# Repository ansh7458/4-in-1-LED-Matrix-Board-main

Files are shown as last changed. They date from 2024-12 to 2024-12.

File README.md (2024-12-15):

# 🎮 4-in-1 LED Matrix Board

<p align="center">
  
  
  
  
  
</p>

> **Centre for Electronic Design and Technology**  
> Netaji Subhas University of Technology, New Delhi  
> *Date: December 2024*

---

## 📋 Table of Contents
- [Synopsis](#-synopsis)
- [Introduction](#-introduction)
- [System Overview](#-system-overview)
- [Working Modes](#-working-modes)
- [Program Logic](#-program-logic)
- [Inputs & Control](#-inputs--control)
- [Bill of Materials](#-bill-of-materials)

---

## 🎯 Synopsis

A compact and multifunctional **5×7 LED dot matrix system** built around an **Arduino Nano**. It integrates **four interactive modules** into a single educational platform:

- 🔤 **Morse Tutor** — Learn Morse code interactively
- ⏳ **LED Hourglass** — Tilt-controlled sand animation
- 👁️ **Persistence of Vision (POV) Demo** — Visual persistence effect
- 🌡️ **Temperature Display** — Real-time thermistor reading

User interaction is achieved via **buttons**, **tilt switches**, and a **potentiometer**. The system leverages **Timer1 CTC interrupts** for flicker-free LED multiplexing.

## 📖 Introduction

LED matrices are widely used in educational and commercial applications. This project creates a single, compact platform that consolidates multiple mini-projects, enabling learners to explore different aspects of embedded system design:

| Mode | Concept Demonstrated |
|---|---|
| Morse Tutor | Digital output control, timing-based signal generation |
| Hourglass | Tilt-sensor input handling, animation sequencing |
| POV Demo | Persistence-of-vision, real-time potentiometer control |
| Temperature | Analog sensor reading, calculation, text rendering |

## 🔧 System Overview

### Block Diagram
<p align="center">
  Block Diagram
</p>

### Pin Assignment (Arduino Nano)

| Pin | Signal | Connected To | Function |
|-----|---|---|---|
| D2-D8 | R1-R7 | ULN2003 | Row drives for LED matrix |
| D9-D13 | C1-C5 | BC327 transistors | Column drives |
| A1-A3 | BTN1-3 | Push Buttons | Navigation (Next/Prev/Select) |
| A4-A5 | Tilt 1-2 | Tilt Switches | Hourglass orientation |
| A6 | Thermistor | NTC | Temperature sensing |
| A7 | Pot | RV1 | POV speed control |

## 🎮 Working Modes

### 1. 🏠 Home Screen
Menu navigation using three push buttons (Next, Previous, Select). Long press (~5s) on Button 1 returns to home from any mode.

### 2. 🔤 Morse Tutor
Displays Morse code patterns for A–Z on the LED matrix with timing-based dot/dash rendering.

### 3. ⏳ Hourglass
Tilt-controlled sand animation with direction detection. Passive buzzer alerts when timer completes.

### 4. 👁️ POV Demo
Potentiometer controls Timer1 compare register, varying refresh frequency to demonstrate persistence-of-vision effect.

### 5. 🌡️ Temperature Display
NTC thermistor with **Beta parameter model** for temperature calculation, displayed as scrolling digits on the matrix.

## ⚙️ Program Logic

The firmware follows a **cooperative architecture**:
- **Foreground (main loop)**: User input processing, mode logic, display buffer updates
- **Background (Timer1 ISR)**: Column-wise LED multiplexing at high speed for flicker-free display

## 📦 Bill of Materials

| S.No | Component | Value | Qty |
|---|---|---|-----|
| 1 | Arduino Nano | — | 1 |
| 2 | 5×7 LED Matrix | — | 1 |
| 3 | ULN2003 | Darlington Array | 1 |
| 4 | BC327 | PNP Transistor | 5 |
| 5 | Push Buttons | — | 3 |
| 6 | Tilt Switches | — | 2 |
| 7 | NTC Thermistor | 10 kΩ | 1 |
| 8 | Potentiometer | — | 1 |
| 9 | Passive Buzzer | — | 1 |

## 🛠️ Technologies Used

`Arduino (C/C++)` · `KiCad` · `Timer Interrupts (CTC)` · `Embedded Systems` · `PCB Design`

## 👥 Author
- **Ansh Gupta** — NSUT, New Delhi

---
*Centre for Electronic Design and Technology, NSUT, New Delhi*

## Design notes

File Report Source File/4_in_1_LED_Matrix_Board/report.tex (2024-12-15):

\documentclass[12pt,a4paper]{article}

% ---------- Packages ----------
\usepackage[utf8]{inputenc}
\usepackage[T1]{fontenc}
\usepackage{lmodern}
\usepackage{geometry}
\geometry{margin=1in}
\usepackage{graphicx}
\usepackage{float}
\usepackage{caption}
\usepackage{subcaption}
\usepackage{siunitx}
\usepackage{booktabs}
\usepackage{array}
\usepackage{amsmath}
\usepackage{hyperref}
\hypersetup{colorlinks=true,allcolors=blue}
\usepackage{enumitem}
\usepackage{xcolor}
\usepackage{listings}
\usepackage{svg}

% ---------- Listings (Arduino/C++) ----------
\lstdefinelanguage{ArduinoC}{language=C++,morekeywords={String,bool,byte,word,bitSet,bitClear,bitWrite,bitRead,analogRead,digitalRead,digitalWrite,pinMode,INPUT,OUTPUT,INPUT_PULLUP,PROGMEM,ISR,cli,sei,tone,noTone}}
\lstset{
  language=ArduinoC,
  basicstyle=\ttfamily\small,
  keywordstyle=\color{blue!70!black}\bfseries,
  commentstyle=\color{gray!70},
  stringstyle=\color{green!50!black},
  showstringspaces=false,
  breaklines=true,
  frame=single,
  tabsize=2,
  captionpos=b,
  numbers=left,
  numberstyle=\tiny\color{gray}
}
\begin{document}
% ---------- Title ----------
\begin{titlepage}
  \begin{center}
    \vspace*{1cm}
    \\[0.5cm]
    {\Large \textbf{Centre for Electronic Design and Technology}}\\[0.25cm]
    {\large Netaji Subhas University of Technology, New Delhi}
    \vfill
    {\Huge \textbf{4-in-1 LED Matrix Board}}\\[0.3cm]
    \vspace{1.5cm}
    {\large \textbf{Submitted by}}\\[0.2cm]
    {\large Ansh Gupta}\\
    \vspace{0.8cm}
    {\large \textbf{Date:} December 2024}
    \vspace*{1cm}
  \end{center}
\end{titlepage}

\tableofcontents
\newpage

% =========================================================
\section{Synopsis}

The project presents a compact and multifunctional 5×7 LED dot matrix system built around an \textbf{Arduino Nano}. It integrates four interactive modules into a single educational platform:

\begin{itemize}
  \item Morse Tutor
  \item LED Hourglass
  \item Persistence of Vision (POV) Demo
  \item Temperature Display
\end{itemize}

User interaction is achieved via buttons, tilt switches, and a potentiometer. The system leverages \textbf{Timer1 CTC interrupts} for flicker-free LED multiplexing and responsive animations. This project serves as a practical tool for learning embedded systems concepts such as sensor interfacing, timer-based control, and display driving on a microcontroller platform.

\section{Introduction}

LED matrices are widely used in educational and commercial applications for visual feedback, animation, and information display. Designing an interactive LED dot matrix system provides hands-on experience in key embedded system concepts, including I/O management, timing control, and analog sensor interfacing.

The motivation behind this project is to create a single, compact platform that consolidates multiple mini-projects, enabling learners to explore different aspects of embedded system design in a cohesive setup. Each module of the system demonstrates a distinct concept:

\begin{itemize}
  \item \textbf{Morse Tutor:} Demonstrates digital output control and timing-based signal generation.
  \item \textbf{Hourglass:} Illustrates tilt-sensor input handling and animation sequencing.
  \item \textbf{POV Demo:} Explores persistence-of-vision techniques and real-time control using potentiometer input.
  \item \textbf{Temperature Display:} Combines analog sensor reading, calculation, and text rendering on a small LED dot matrix.
\end{itemize}

This report details the hardware and software design of the system, the logic behind each functional mode, and the observed performance, highlighting the educational value of integrating multiple embedded system principles into one device.

% =========================================================
\section{System Overview}
\subsection{Block Diagram}
\begin{figure}[H]
  \centering
  % Replace with your block diagram file
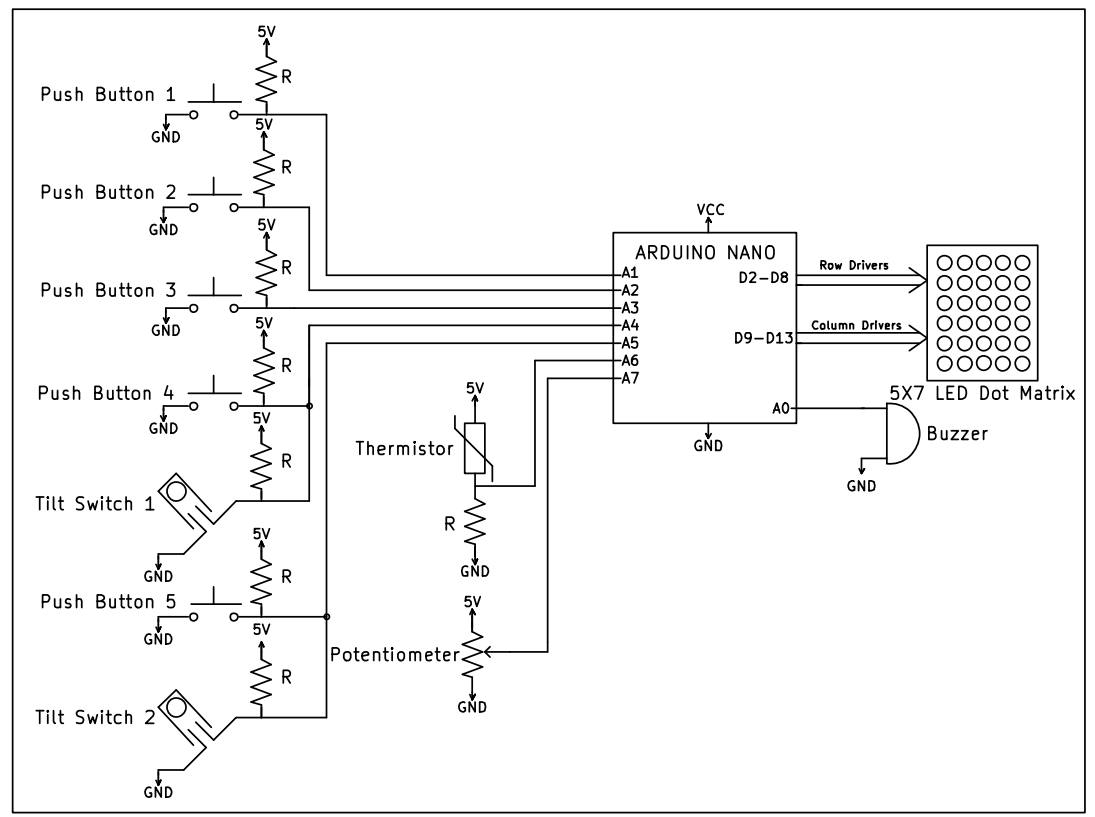
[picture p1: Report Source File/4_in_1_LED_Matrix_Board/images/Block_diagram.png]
  
  \caption{Block diagram}
  \label{fig:block}
\end{figure}

\subsection{Schematic Diagram}
\begin{figure}[H]
  \centering
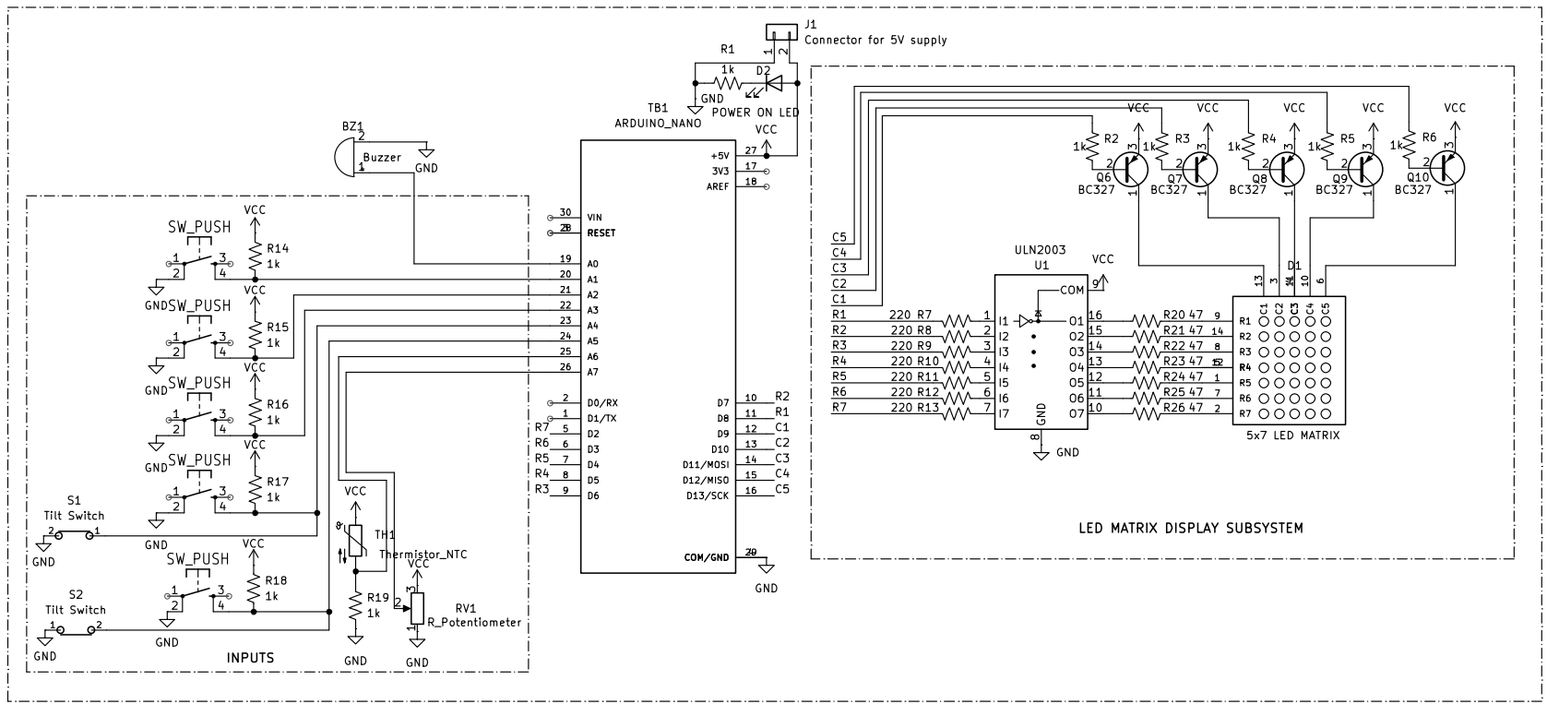
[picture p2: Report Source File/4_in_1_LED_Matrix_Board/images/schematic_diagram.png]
  
  \caption{Schematic Diagram}
  \label{fig:schematic}
\end{figure}
%=========================================================
\subsection{Pin Assignment Table}

Table~\ref{tab:pinout} summarizes the Arduino Nano pin assignments and their corresponding peripherals used in the 4-in-1 LED Matrix Board.

\begin{table}[H]
\centering
\caption{Arduino Nano Pin Assignment}
\label{tab:pinout}
\renewcommand{\arraystretch}{1.2}
\begin{tabular}{cllp{6.5cm}}
\toprule
\textbf{Pin} & \textbf{Signal} & \textbf{Connected To} & \textbf{Function} \\
\midrule

D2  & R7 & ULN2003 IN7 & Drives Row 7 of the LED matrix \\
D3  & R6 & ULN2003 IN6 & Drives Row 6 of the LED matrix \\
D4  & R5 & ULN2003 IN5 & Drives Row 5 of the LED matrix \\
D5  & R4 & ULN2003 IN4 & Drives Row 4 of the LED matrix \\
D6  & R3 & ULN2003 IN3 & Drives Row 3 of the LED matrix \\
D7  & R2 & ULN2003 IN2 & Drives Row 2 of the LED matrix \\
D8  & R1 & ULN2003 IN1 & Drives Row 1 of the LED matrix \\

D9  & C1 & Matrix Column 1 & Column drive through BC327 transistor \\
D10 & C2 & Matrix Column 2 & Column drive through BC327 transistor \\
D11 & C3 & Matrix Column 3 & Column drive through BC327 transistor \\
D12 & C4 & Matrix Column 4 & Column drive through BC327 transistor \\
D13 & C5 & Matrix Column 5 & Column drive through BC327 transistor \\

A0 & -- & Not Used & Reserved / unused \\

A1 & BTN1 & Push Button 1 & Home navigation (Next) \\
A2 & BTN2 & Push Button 2 & Home navigation (Previous) \\
A3 & BTN3 & Push Button 3 & Home navigation (Select) \\
A4 & Tilt 1 & Tilt Switch S1/ Push Button 4 & Hourglass tilt input \\
A5 & Tilt 2 & Tilt Switch S2/ Push Button 5 & Reverse hourglass tilt input \\
A6 & Thermistor & NTC Thermistor & Temperature sensing \\
A7 & Potentiometer & RV1 & Controls POV display speed \\

5V & VCC & All peripherals & Supply voltage \\
GND & GND & Entire circuit & Common ground \\

\bottomrule
\end{tabular}
\end{table}
% =========================================================
\section{Program Logic}
\begin{figure}[H]
  \centering
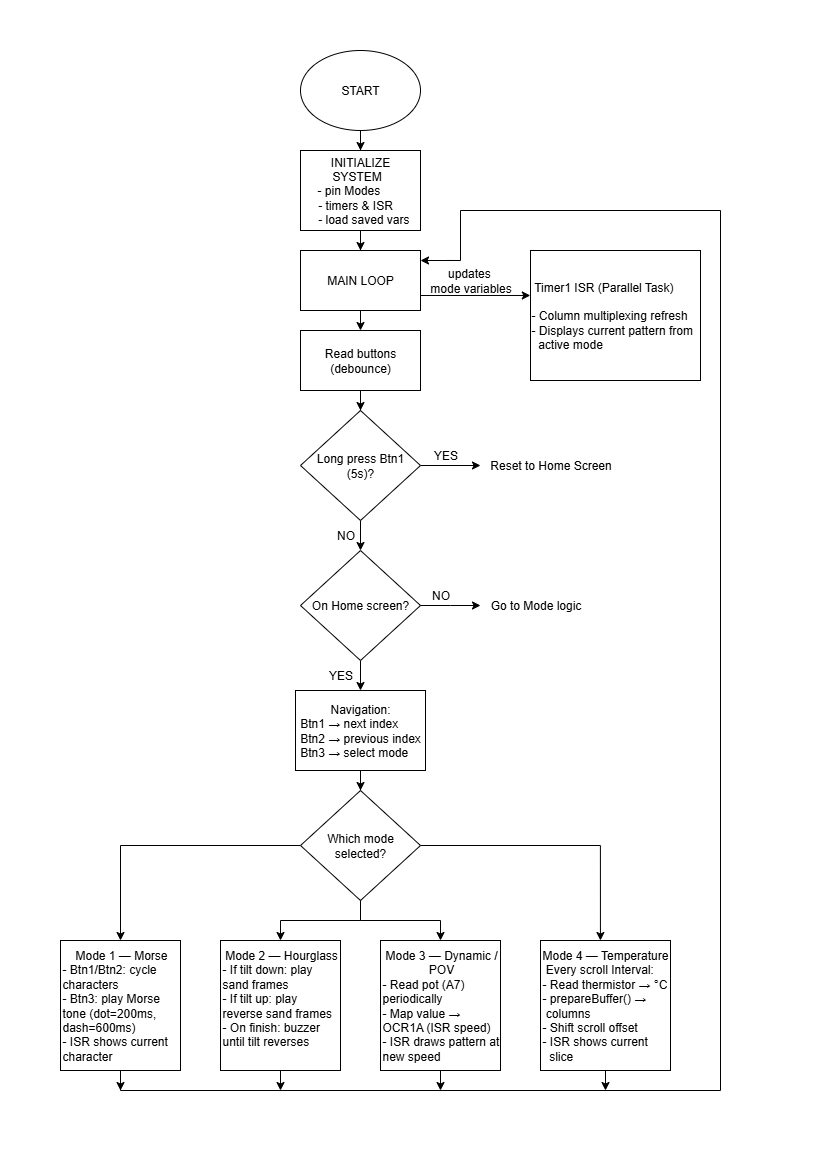
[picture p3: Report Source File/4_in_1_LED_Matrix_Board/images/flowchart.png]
  
  \caption{High-level program flowchart showing initialization, main loop logic, and Timer1 ISR operation.}
\end{figure}
\newpage
After power-up or reset, the firmware configures all GPIO pins, initializes global variables, computes the timing parameters required for animation modes, and configures \textbf{Timer1} in \textbf{Clear Timer on Compare (CTC)} mode. Timer1 generates periodic interrupts that continuously refresh the LED matrix using column-wise multiplexing, allowing the main program to execute application logic independently of display updates.

The firmware follows a cooperative architecture consisting of a foreground \textbf{main loop} and a background \textbf{Timer1 Interrupt Service Routine (ISR)}. The main loop is responsible for processing user inputs, updating mode-specific variables, and preparing display data, while the ISR performs high-speed multiplexing of the LED matrix to maintain a stable, flicker-free display.

The overall firmware operation is summarized below.

\begin{enumerate}[itemsep=4pt]

\item \textbf{Home Screen Navigation:}
When no application mode is active, the LED matrix displays the home screen. Three push buttons are used for menu navigation:
\begin{itemize}
    \item Button~1 -- Next mode
    \item Button~2 -- Previous mode
    \item Button~3 -- Select mode
\end{itemize}
A long press of Button~1 (approximately 5\,s) exits any running mode and returns the system to the home screen.

\item \textbf{Mode Execution:}
After a mode is selected, the corresponding application logic executes within the main loop.
\begin{itemize}
    \item \textbf{Mode 1:} Morse Tutor
    \item \textbf{Mode 2:} LED Hourglass
    \item \textbf{Mode 3:} Persistence of Vision (POV) Demo
    \item \textbf{Mode 4:} Temperature Display
\end{itemize}

\item \textbf{Background Display Refresh:}
The Timer1 ISR executes periodically throughout system operation. During each interrupt, one column of the LED matrix is refreshed by outputting the appropriate bitmap corresponding to the currently active mode. This interrupt-driven multiplexing ensures uniform brightness and prevents visible display flicker.

\item \textbf{Foreground Processing:}
While the ISR refreshes the display, the main loop continuously performs button debouncing, tilt-switch monitoring, potentiometer and thermistor acquisition, mode transitions, animation control, and updates the display buffer whenever the displayed content changes.

\end{enumerate}
\newpage
% =========================================================
\section{Inputs and Control Logic}
\subsection{Buttons and Navigation}

Three push buttons provide user interaction with the system. Each button is configured using the Arduino Nano's internal \texttt{INPUT\_PULLUP} resistor, eliminating the need for external pull-down resistors and ensuring a stable default logic HIGH state. Consequently, a button press is detected as a logic LOW (active LOW).

During Home Screen operation, Button~1 and Button~2 are used to navigate through the available modes, while Button~3 selects the highlighted mode. To improve usability, the firmware also detects a long press (approximately 5\,s) on Button~1, allowing the user to exit any active mode and return directly to the Home Screen.

\subsection{Tilt Interaction}

The Hourglass mode uses two tilt switches to detect the orientation of the board. Each switch is configured as an active LOW digital input using the Arduino Nano's internal pull-up resistor. Depending on the detected orientation, the firmware determines the direction of the sand animation.

\begin{itemize}[itemsep=2pt]
    \item When the board is tilted downward, the sand animation is played in the forward direction, simulating sand falling to the bottom chamber.
    
    \item When the board is tilted upward, the animation is played in the reverse direction, simulating the hourglass being inverted.
    
    \item After the final animation frame is displayed, the passive buzzer generates an audible alert. The alert continues until the board is tilted in the opposite direction or the mode is reset.
\end{itemize}
\textbf{Note:} The tilt switches are connected to Arduino Nano pins \textbf{A4} and \textbf{A5}, which are also routed to \textbf{Button~4} and \textbf{Button~5}, respectively, on the development board. These pins are dedicated to tilt sensing in the current implementation and are therefore not used as general-purpose push buttons.

\subsection{Potentiometer and Display Refresh Control}

The Persistence of Vision (POV) mode uses a potentiometer to provide real-time control over the display refresh rate. The potentiometer output is continuously sampled through the Arduino Nano's ADC, and the measured value is used to adjust the Timer1 compare register (\texttt{OCR1A}).

Modifying the Timer1 compare value changes the interrupt period, thereby varying the LED matrix refresh frequency. At higher refresh rates, the displayed character appears stable due to the persistence-of-vision effect, whereas lower refresh rates make the row-by-row multiplexing process visible. This provides an interactive demonstration of how refresh frequency influences the perceived display.
\newpage

\subsection{Thermistor and Temperature Calculation}

Temperature measurement is performed using an NTC thermistor connected in a voltage divider configuration with a fixed \SI{1}{k\ohm} resistor. The Arduino Nano measures the divider voltage using its ADC, from which the thermistor resistance is calculated. The resistance is then converted into temperature using the \textbf{Beta parameter model}, which provides a good balance between computational simplicity and measurement accuracy for NTC thermistors.

The thermistor resistance is calculated as

\[
R_\mathrm{th}=R_\mathrm{pullup}\frac{5-V}{V},
\]

where \(V\) is the measured divider voltage.

The temperature in Kelvin is then obtained using

\[
T(K)=
\frac{1}
{\dfrac{1}{T_0}+
\dfrac{1}{\beta}
\ln\left(\dfrac{R_\mathrm{th}}{R_0}\right)},
\]

where

\[
T_0=298.15~\mathrm{K}, \qquad
\beta=3950, \qquad
R_0=\SI{1}{k\ohm}, \qquad
R_\mathrm{pullup}=\SI{1}{k\ohm}.
\]

The calculated temperature is converted to degrees Celsius and formatted into a scrolling text buffer using the \texttt{prepareBuffer()} function before being displayed on the LED matrix.
\newpage

% =========================================================
\section{Working Modes}

\subsection{Home Screen}

The Home Screen serves as the primary user interface of the system. It displays five icons corresponding to the available operating modes: Home, Morse Tutor, Hourglass, Persistence of Vision (POV) Demo, and Temperature Display. Users can navigate between these icons using Button~1 and Button~2, while Button~3 selects the highlighted mode. A long press of Button~1 returns the system to the Home Screen from any active mode.

\begin{figure}[H]
  \centering
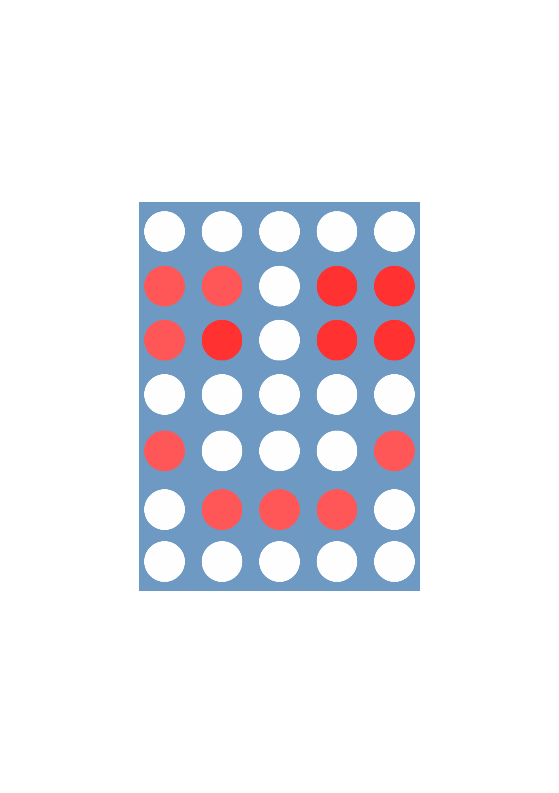
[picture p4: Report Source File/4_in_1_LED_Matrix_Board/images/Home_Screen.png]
  
  \caption{Home screen icons on the 5$\times$7 matrix.}
\end{figure}
\newpage
\subsection{Mode 1: Morse Tutor}

\begin{itemize}[itemsep=2pt]

\item \textbf{Selection:} Buttons~1 and~2 are used to cycle through the supported alphanumeric characters (A--Z and 0--9). Button~3 transmits the selected character as Morse code.

\item \textbf{Operation:} Each character is encoded according to the International Morse Code standard. A dot is represented by a \SI{200}{ms} tone, while a dash is represented by a \SI{600}{ms} tone. The corresponding sequence is generated through the onboard passive buzzer.

\item \textbf{Display:} The selected character is simultaneously displayed on the 5$\times$7 LED matrix, allowing users to associate the visual character with its corresponding Morse code representation.

\end{itemize}

\begin{figure}[H]
  \centering
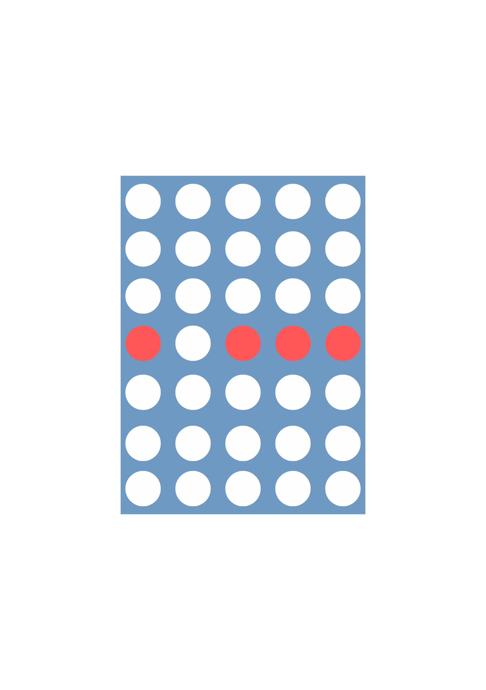
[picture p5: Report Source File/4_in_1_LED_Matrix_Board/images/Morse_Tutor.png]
  
  \caption{Morse Tutor mode glyph preview.}
\end{figure}
\newpage
\subsection{Mode 2: Hourglass}
\begin{itemize}[itemsep=2pt]

\item \textbf{Animation:} The LED matrix displays a sequence of pre-defined bitmap frames that simulate sand flowing between the two chambers of an hourglass.

\item \textbf{Control:} Two tilt switches detect the orientation of the board. Tilting the board upward or downward causes the animation to play in the corresponding direction, emulating the inversion of a physical hourglass.

\item \textbf{Alert:} Once the animation reaches its final frame, the passive buzzer generates a continuous audible alert. The alert remains active until the board is tilted in the opposite direction or the mode is reset.

\end{itemize}

\begin{figure}[H]
  \centering
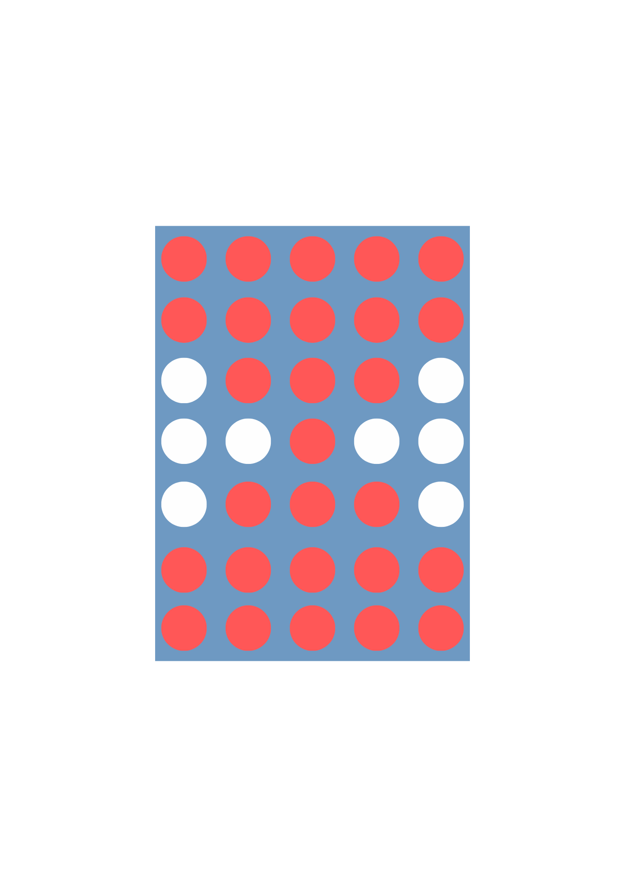
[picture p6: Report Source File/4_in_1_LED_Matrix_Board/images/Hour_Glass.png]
  
  \caption{Hourglass mode glyph preview.}
\end{figure}
\newpage
\subsection{Mode 3: POV Demo}
\begin{itemize}[itemsep=2pt]

\item \textbf{Concept:} This mode demonstrates the principle of Persistence of Vision (POV), where the LED matrix is refreshed at a sufficiently high frequency to create the perception of a stable, continuous image.

\item \textbf{Control:} The display refresh rate is controlled using a potentiometer. By varying the Timer1 interrupt period, the user can adjust the matrix scanning speed, allowing the transition from a flicker-free display to visible row-by-row multiplexing to be observed.

\item \textbf{Display:} A demonstration character is displayed on the LED matrix to illustrate the persistence-of-vision effect. The displayed bitmap can be replaced with any user-defined pattern.

\end{itemize}

\begin{figure}[H]
  \centering
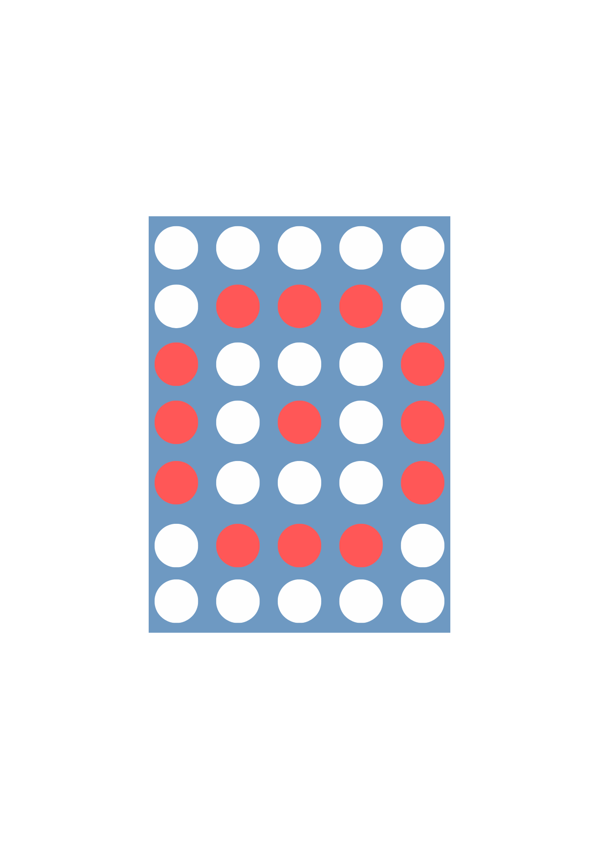
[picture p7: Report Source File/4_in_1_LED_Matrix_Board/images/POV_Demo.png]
  
  \caption{POV Demo mode glyph preview.}
\end{figure}
\newpage
\subsection{Mode 4: Temperature Display}
\begin{itemize}[itemsep=2pt]

\item \textbf{Acquisition:} The thermistor is periodically sampled using the Arduino Nano's analog-to-digital converter (ADC). The measured voltage is converted into temperature using the Beta parameter model described in Section~5.4.

\item \textbf{Rendering:} The calculated temperature is formatted as a text string and converted into a bitmap representation suitable for display on the 5$\times$7 LED matrix.

\item \textbf{Scrolling:} Since the display is limited to five columns, the temperature is presented as a horizontally scrolling message, allowing the complete value to be viewed continuously.

\end{itemize}

\begin{figure}[H]
  \centering
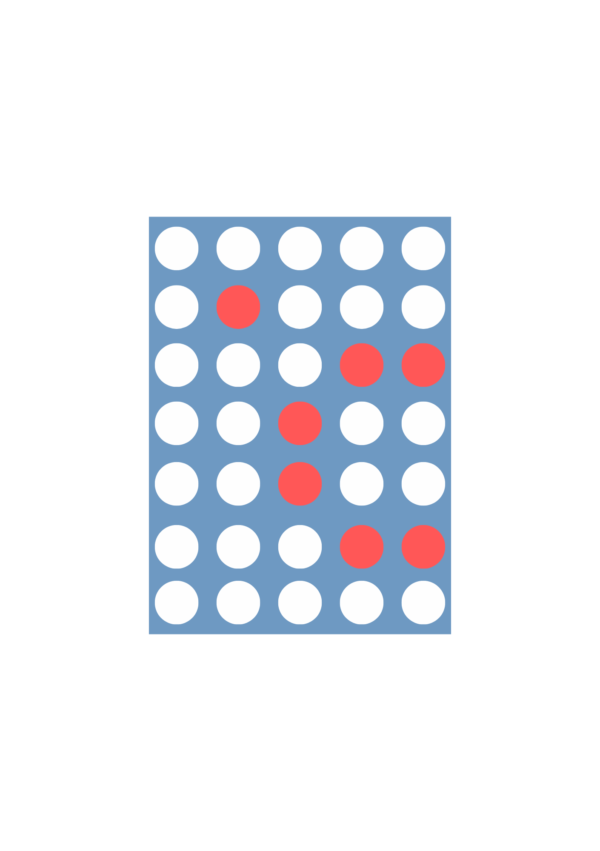
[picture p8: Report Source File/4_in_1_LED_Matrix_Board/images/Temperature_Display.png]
  
  \caption{Temperature Display mode glyph preview.}
\end{figure}
\newpage

\section{Bill Of Material(BOM)}

\begin{figure}[H]
  \centering
  \includegraphics[width=1
  \textwidth]{images/BOM.png}
  \caption{Bill of Material}
\end{figure}
\newpage
% =========================================================
\section{Result}
\begin{figure}[H]
  \centering
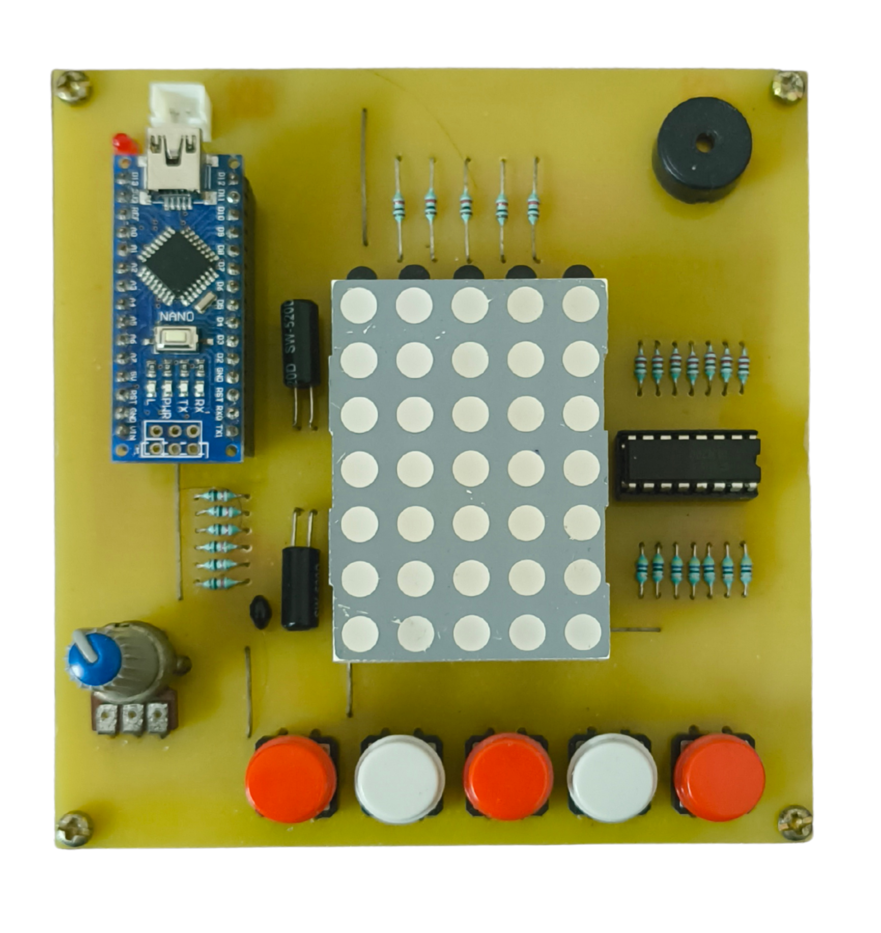
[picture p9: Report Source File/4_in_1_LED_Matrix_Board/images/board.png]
  
  \caption{4-in-1 LED Matrix Board}
\end{figure}
% =========================================================

% =========================================================
\section*{Appendix}

\subsection*{Code Files}
\begin{itemize}
  \item \href{https://drive.google.com/drive/folders/18NrzdcTJGfZFWStb0k2ivs41fUbuqQW8?usp=drive_link}{Arduino Sketch}
\end{itemize}
\vspace{-2mm}

\subsection*{Datasheets}
\begin{itemize}
  \item \href{https://drive.google.com/drive/folders/1ehxPydzgNhIfgLCbERb8SDw7-o424vQl?usp=drive_link}{ULN2003}
  \end{itemize}
  \begin{itemize}
  \item \href{https://docs.arduino.cc/hardware/nano/}{Arduino NANO}
  \end{itemize}

\end{document}

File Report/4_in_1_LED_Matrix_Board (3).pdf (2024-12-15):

## Centre for Electronic Design and Technology

### Netaji Subhas University of Technology, New Delhi

# 4-in-1 LED Matrix Board

### Submitted by

### Ansh Gupta

### Date: December 2024

## Contents

1 Synopsis | 2
2 Introduction | 2
3 System Overview | 3
4 Program Logic | 6
5 Inputs and Control Logic | 8
6 Working Modes | 10
7 Bill Of Material(BOM) | 15
8 Result | 16
9 Appendix | 16

## 1 Synopsis

The project presents a compact and multifunctional 5×7 LED dot matrix system built around an Arduino Nano. It integrates four interactive modules into a single educational platform:

- Morse Tutor
- LED Hourglass
- Persistence of Vision (POV) Demo
- Temperature Display

User interaction is achieved via buttons, tilt switches, and a potentiometer. The system leverages Timer1 CTC interrupts for flicker-free LED multiplexing and responsive animations. This project serves as a practical tool for learning embedded systems concepts such as sensor interfacing, timer-based control, and display driving on a microcontroller platform.

## 2 Introduction

LED matrices are widely used in educational and commercial applications for visual feedback, animation, and information display. Designing an interactive LED dot matrix system provides hands-on experience in key embedded system concepts, including I/O management, timing control, and analog sensor interfacing.
The motivation behind this project is to create a single, compact platform that consolidates multiple mini-projects, enabling learners to explore different aspects of embedded system design in a cohesive setup. Each module of the system demonstrates a distinct concept:
- Morse Tutor: Demonstrates digital output control and timing-based signal generation.
- Hourglass: Illustrates tilt-sensor input handling and animation sequencing.
- POV Demo: Explores persistence-of-vision techniques and real-time control using potentiometer input.
- Temperature Display: Combines analog sensor reading, calculation, and text rendering on a small LED dot matrix.

This report details the hardware and software design of the system, the logic behind each functional mode, and the observed performance, highlighting the educational value of integrating multiple embedded system principles into one device.

## 3 System Overview

### 3.1 Block Diagram


Figure 1: Block diagram

### 3.2 Schematic Diagram

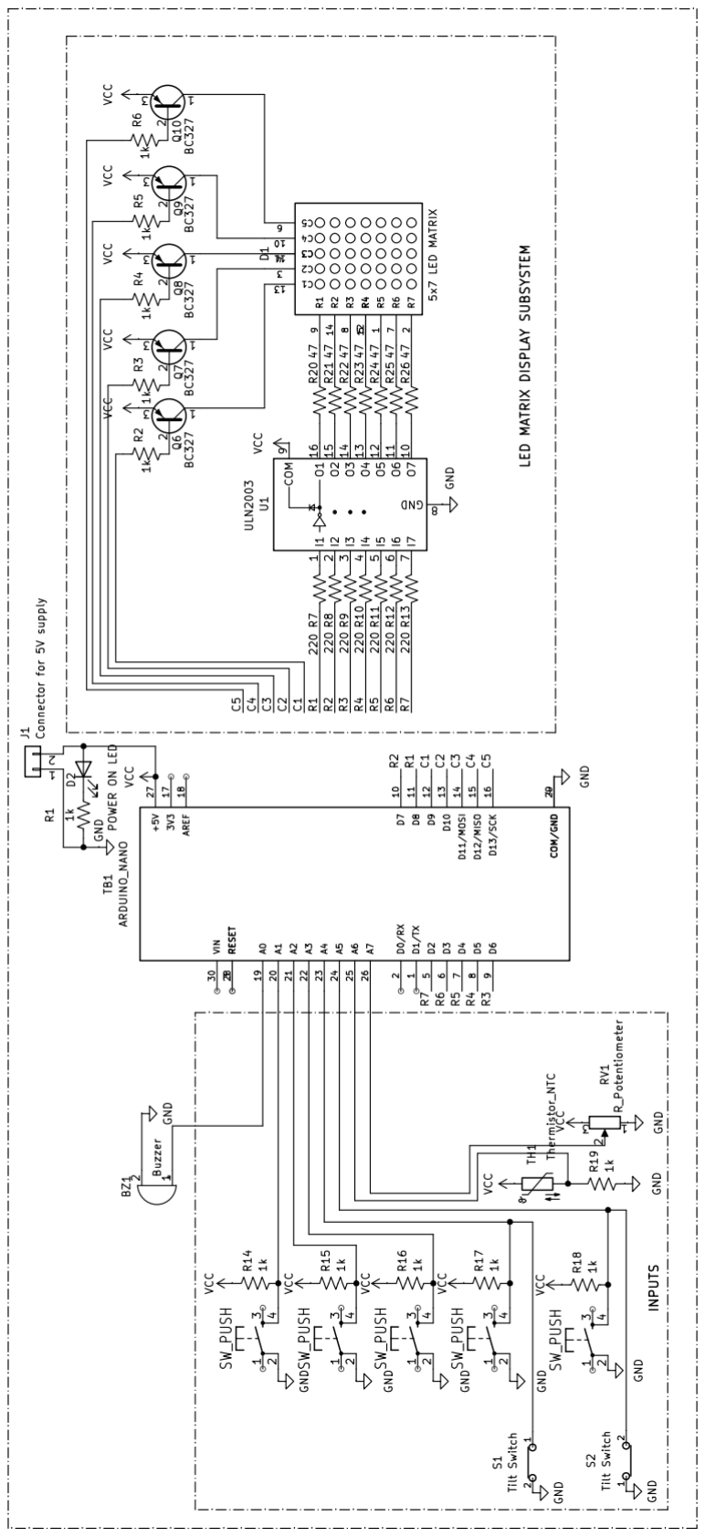
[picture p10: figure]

Figure 2: Schematic Diagram

### 3.3 Pin Assignment Table

Table 1 summarizes the Arduino Nano pin assignments and their corresponding peripherals used in the 4-in-1 LED Matrix Board.

Table 1: Arduino Nano Pin Assignment

Pin | Signal | Connected To | Function
D2 | R7 | ULN2003 IN7 | Drives Row 7 of the LED matrix
D3 | R6 | ULN2003 IN6 | Drives Row 6 of the LED matrix
D4 | R5 | ULN2003 IN5 | Drives Row 5 of the LED matrix
D5 | R4 | ULN2003 IN4 | Drives Row 4 of the LED matrix
D6 | R3 | ULN2003 IN3 | Drives Row 3 of the LED matrix
D7 | R2 | ULN2003 IN2 | Drives Row 2 of the LED matrix
D8 | R1 | ULN2003 IN1 | Drives Row 1 of the LED matrix
D9 | C1 | Matrix Column 1 | Column drive through BC327 tran- sistor
D10 | C2 | Matrix Column 2 | Column drive through BC327 tran- sistor
D11 | C3 | Matrix Column 3 | Column drive through BC327 tran- sistor
D12 | C4 | Matrix Column 4 | Column drive through BC327 tran- sistor
D13 | C5 | Matrix Column 5 | Column drive through BC327 tran- sistor
A0 | – | Not Used | Reserved / unused
A1 | BTN1 | Push Button 1 | Home navigation (Next)
A2 | BTN2 | Push Button 2 | Home navigation (Previous)
A3 | BTN3 | Push Button 3 | Home navigation (Select)
A4 | Tilt 1 | Tilt Switch S1/ Push Button 4 Hourglass tilt input
A5 | Tilt 2 | Tilt Switch S2/ Push Button 5 Reverse hourglass tilt input
A6 | Thermistor | NTC Thermistor | Temperature sensing
A7 | Potentiometer RV1 | Controls POV display speed
5V | VCC | All peripherals | Supply voltage
GND GND | Entire circuit | Common ground

## 4 Program Logic

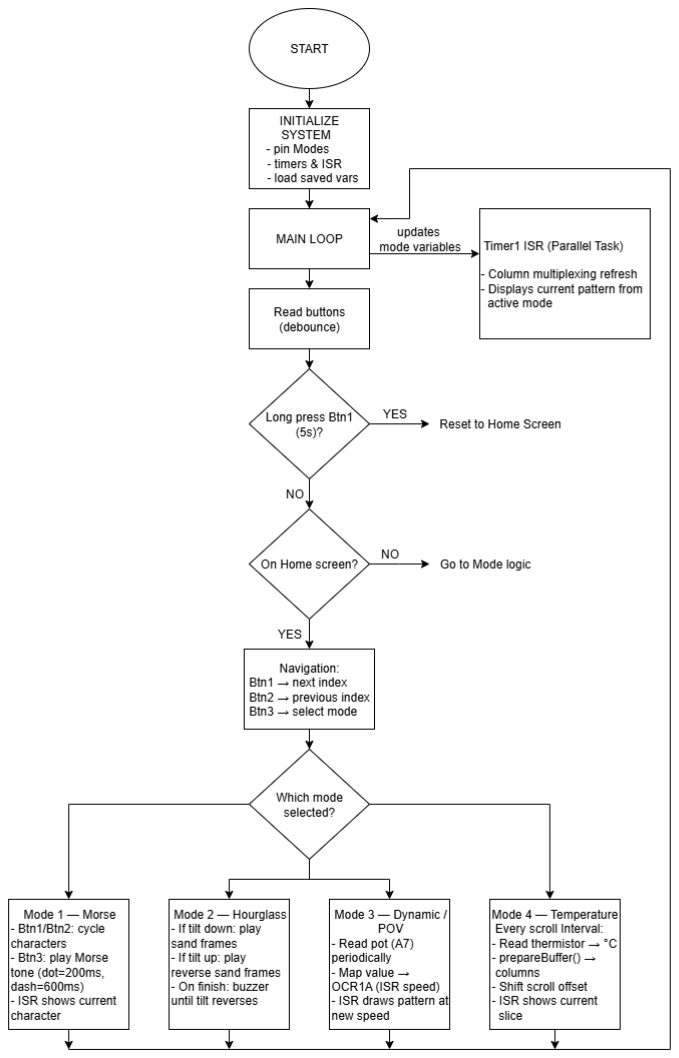
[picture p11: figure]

Figure 3: High-level program flowchart showing initialization, main loop logic, and Timer1 ISR operation.

After power-up or reset, the firmware configures all GPIO pins, initializes global variables, computes the timing parameters required for animation modes, and configures Timer1 in Clear Timer on Compare (CTC) mode. Timer1 generates periodic interrupts that continuously refresh the LED matrix using column-wise multiplexing, allowing the main program to execute application logic independently of display updates.
The firmware follows a cooperative architecture consisting of a foreground main loop and a background Timer1 Interrupt Service Routine (ISR). The main loop is responsible for processing user inputs, updating mode-specific variables, and preparing display data, while the ISR performs high-speed multiplexing of the LED matrix to maintain a stable, flicker-free display.
The overall firmware operation is summarized below.
1. Home Screen Navigation: When no application mode is active, the LED matrix displays the home screen. Three push buttons are used for menu navigation:
- Button 1 – Next mode
- Button 2 – Previous mode
- Button 3 – Select mode

A long press of Button 1 (approximately 5 s) exits any running mode and returns the system to the home screen.

2. Mode Execution: After a mode is selected, the corresponding application logic executes within the main loop.
- Mode 1: Morse Tutor
- Mode 2: LED Hourglass
- Mode 3: Persistence of Vision (POV) Demo
- Mode 4: Temperature Display
3. Background Display Refresh: The Timer1 ISR executes periodically throughout system operation. During each interrupt, one column of the LED matrix is refreshed by outputting the appropriate bitmap corresponding to the currently active mode. This interrupt-driven multiplexing ensures uniform brightness and prevents visible display flicker.
4. Foreground Processing: While the ISR refreshes the display, the main loop continuously performs button debouncing, tilt-switch monitoring, potentiometer and thermistor acquisition, mode transitions, animation control, and updates the display buffer whenever the displayed content changes.

## 5 Inputs and Control Logic

### 5.1 Buttons and Navigation

Three push buttons provide user interaction with the system. Each button is configured using the Arduino Nano’s internal INPUT_PULLUP resistor, eliminating the need for external pull-down resistors and ensuring a stable default logic HIGH state. Consequently, a button press is detected as a logic LOW (active LOW).
During Home Screen operation, Button 1 and Button 2 are used to navigate through the available modes, while Button 3 selects the highlighted mode. To improve usability, the firmware also detects a long press (approximately 5 s) on Button 1, allowing the user to exit any active mode and return directly to the Home Screen.

### 5.2 Tilt Interaction

The Hourglass mode uses two tilt switches to detect the orientation of the board. Each switch is configured as an active LOW digital input using the Arduino Nano’s internal pull-up resistor. Depending on the detected orientation, the firmware determines the direction of the sand animation.

- When the board is tilted downward, the sand animation is played in the forward direction, simulating sand falling to the bottom chamber.
- When the board is tilted upward, the animation is played in the reverse direction, simulating the hourglass being inverted.
- After the final animation frame is displayed, the passive buzzer generates an audible alert. The alert continues until the board is tilted in the opposite direction or the mode is reset.

Note: The tilt switches are connected to Arduino Nano pins A4 and A5, which are also routed to Button 4 and Button 5, respectively, on the development board. These pins are dedicated to tilt sensing in the current implementation and are therefore not used as general-purpose push buttons.

### 5.3 Potentiometer and Display Refresh Control

The Persistence of Vision (POV) mode uses a potentiometer to provide real-time control over the display refresh rate. The potentiometer output is continuously sampled through the Arduino Nano’s ADC, and the measured value is used to adjust the Timer1 compare register (OCR1A).
Modifying the Timer1 compare value changes the interrupt period, thereby varying the LED matrix refresh frequency. At higher refresh rates, the displayed character appears stable due to the persistence-of-vision effect, whereas lower refresh rates make the rowby-row multiplexing process visible. This provides an interactive demonstration of how refresh frequency influences the perceived display.

### 5.4 Thermistor and Temperature Calculation

Temperature measurement is performed using an NTC thermistor connected in a voltage divider configuration with a fixed 1 kW resistor. The Arduino Nano measures the divider voltage using its ADC, from which the thermistor resistance is calculated. The resistance is then converted into temperature using the Beta parameter model, which provides a good balance between computational simplicity and measurement accuracy for NTC thermistors.
The thermistor resistance is calculated as

Rth = Rpullup

5 − V
V

,

where V is the measured divider voltage.
The temperature in Kelvin is then obtained using
T(K) = | 1
1
T0

+

1
β
| ln Rth
R0

,

where

T0 = 298.15 K, | β = 3950, | R0 = 1 kΩ, | Rpullup = 1 kΩ.

The calculated temperature is converted to degrees Celsius and formatted into a scrolling text buffer using the prepareBuffer() function before being displayed on the LED matrix.

## 6 Working Modes

### 6.1 Home Screen

The Home Screen serves as the primary user interface of the system. It displays five icons corresponding to the available operating modes: Home, Morse Tutor, Hourglass, Persistence of Vision (POV) Demo, and Temperature Display. Users can navigate between these icons using Button 1 and Button 2, while Button 3 selects the highlighted mode. A long press of Button 1 returns the system to the Home Screen from any active mode.


Figure 4: Home screen icons on the 5×7 matrix.

### 6.2 Mode 1: Morse Tutor

- Selection: Buttons 1 and 2 are used to cycle through the supported alphanumeric characters (A–Z and 0–9). Button 3 transmits the selected character as Morse code.
- Operation: Each character is encoded according to the International Morse Code standard. A dot is represented by a 200 ms tone, while a dash is represented by a 600 ms tone. The corresponding sequence is generated through the onboard passive buzzer.
- Display: The selected character is simultaneously displayed on the 5×7 LED matrix, allowing users to associate the visual character with its corresponding Morse code representation.


Figure 5: Morse Tutor mode glyph preview.

### 6.3 Mode 2: Hourglass

- Animation: The LED matrix displays a sequence of pre-defined bitmap frames that simulate sand flowing between the two chambers of an hourglass.
- Control: Two tilt switches detect the orientation of the board. Tilting the board upward or downward causes the animation to play in the corresponding direction, emulating the inversion of a physical hourglass.
- Alert: Once the animation reaches its final frame, the passive buzzer generates a continuous audible alert. The alert remains active until the board is tilted in the opposite direction or the mode is reset.


Figure 6: Hourglass mode glyph preview.

### 6.4 Mode 3: POV Demo

- Concept: This mode demonstrates the principle of Persistence of Vision (POV), where the LED matrix is refreshed at a sufficiently high frequency to create the perception of a stable, continuous image.
- Control: The display refresh rate is controlled using a potentiometer. By varying the Timer1 interrupt period, the user can adjust the matrix scanning speed, allowing the transition from a flicker-free display to visible row-by-row multiplexing to be observed.
- Display: A demonstration character is displayed on the LED matrix to illustrate the persistence-of-vision effect. The displayed bitmap can be replaced with any user-defined pattern.


Figure 7: POV Demo mode glyph preview.

### 6.5 Mode 4: Temperature Display

- Acquisition: The thermistor is periodically sampled using the Arduino Nano’s analog-to-digital converter (ADC). The measured voltage is converted into temperature using the Beta parameter model described in Section 5.4.
- Rendering: The calculated temperature is formatted as a text string and converted into a bitmap representation suitable for display on the 5×7 LED matrix.
- Scrolling: Since the display is limited to five columns, the temperature is presented as a horizontally scrolling message, allowing the complete value to be viewed continuously.


Figure 8: Temperature Display mode glyph preview.

## 7 Bill Of Material(BOM)

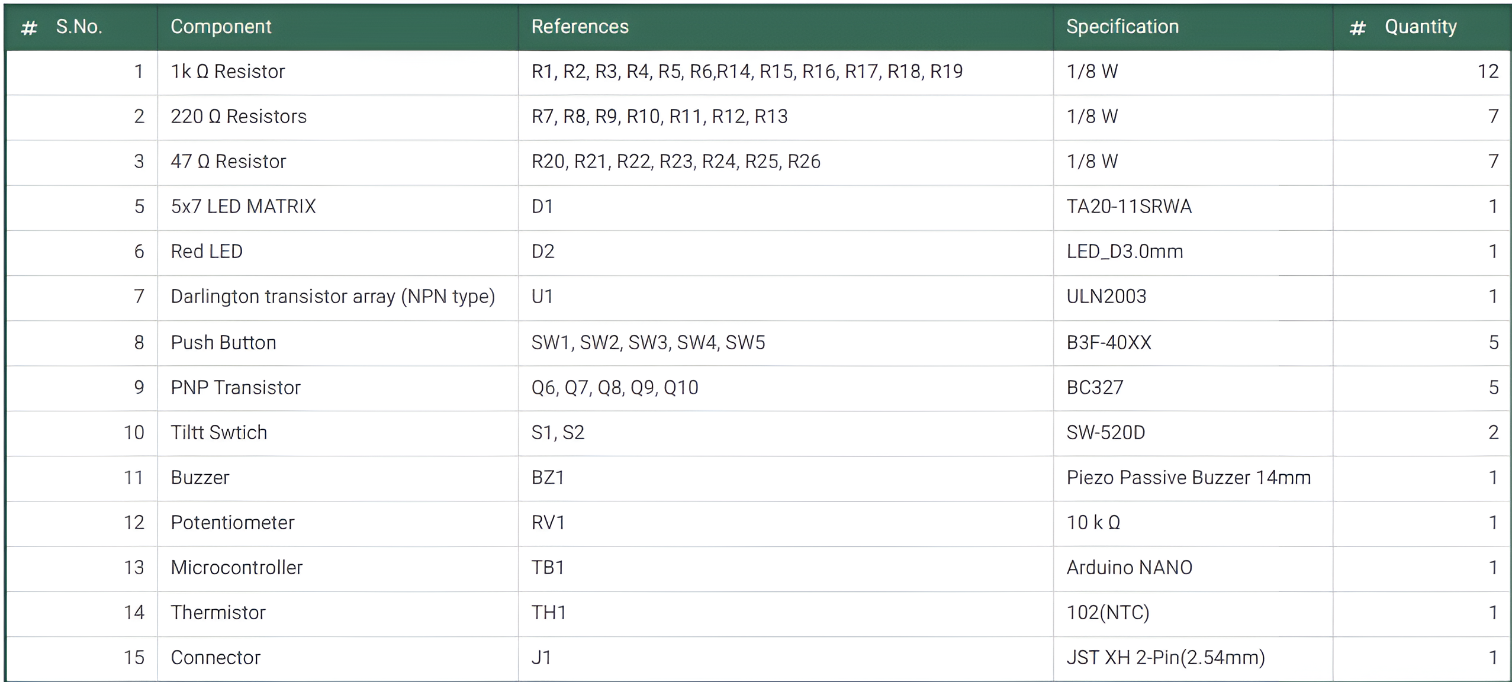
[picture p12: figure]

Figure 9: Bill of Material

## 8 Result

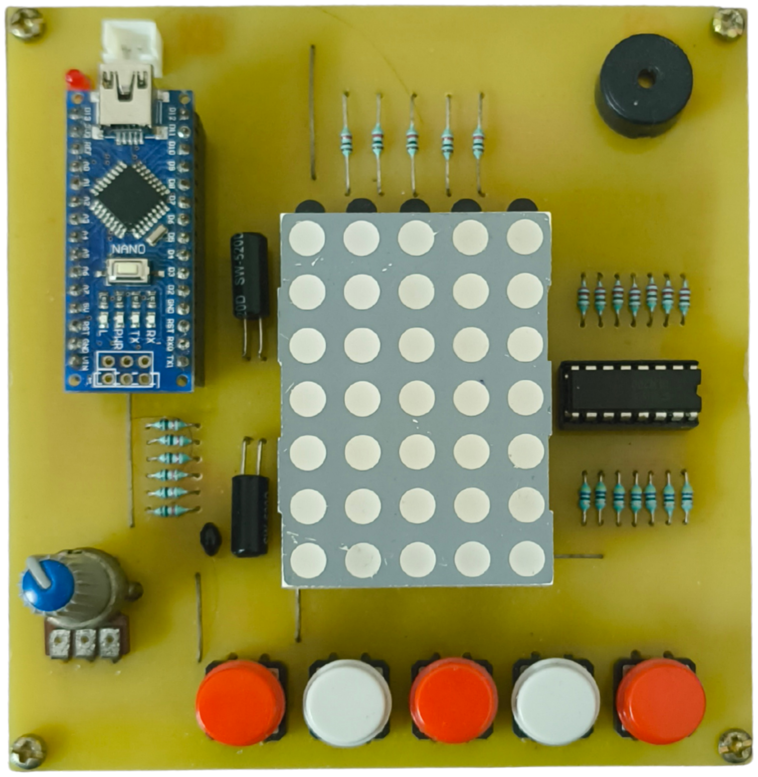
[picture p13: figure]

Figure 10: 4-in-1 LED Matrix Board

## 9 Appendix

### 9.1 Code Files

- Arduino Sketch (https://drive.google.com/drive/folders/18NrzdcTJGfZFWStb0k2ivs41fUbuqQW8?usp=drive_link)

### 9.2 Datasheets

- ULN2003 (https://drive.google.com/drive/folders/1ehxPydzgNhIfgLCbERb8SDw7-o424vQl?usp=drive_link)
- Arduino NANO (https://docs.arduino.cc/hardware/nano/)

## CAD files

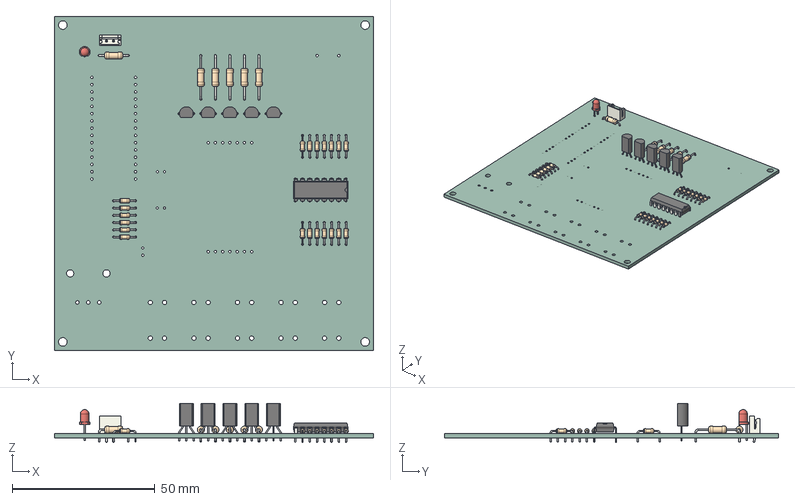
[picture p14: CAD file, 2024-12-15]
Kicad Files/4-in-1_LED_Matrix_Board/4-in-1_LED_Matrix_Board.step
111.8 x 116.8 x 13.8 mm
R_Axial_DIN0204_L36mm_D16mm_P762mm_Horizontal x 20
R_Axial_DIN0207_L63mm_D25mm_P1524mm_Horizontal x 5
LED_D3.0mm
TO-92L_Inline_Wide x 5
JST_B2B_EH_A
R_Axial_DIN0207_L63mm_D25mm_P1016mm_Horizontal
DIP-16_W7.62mm
matrix_2_PCB

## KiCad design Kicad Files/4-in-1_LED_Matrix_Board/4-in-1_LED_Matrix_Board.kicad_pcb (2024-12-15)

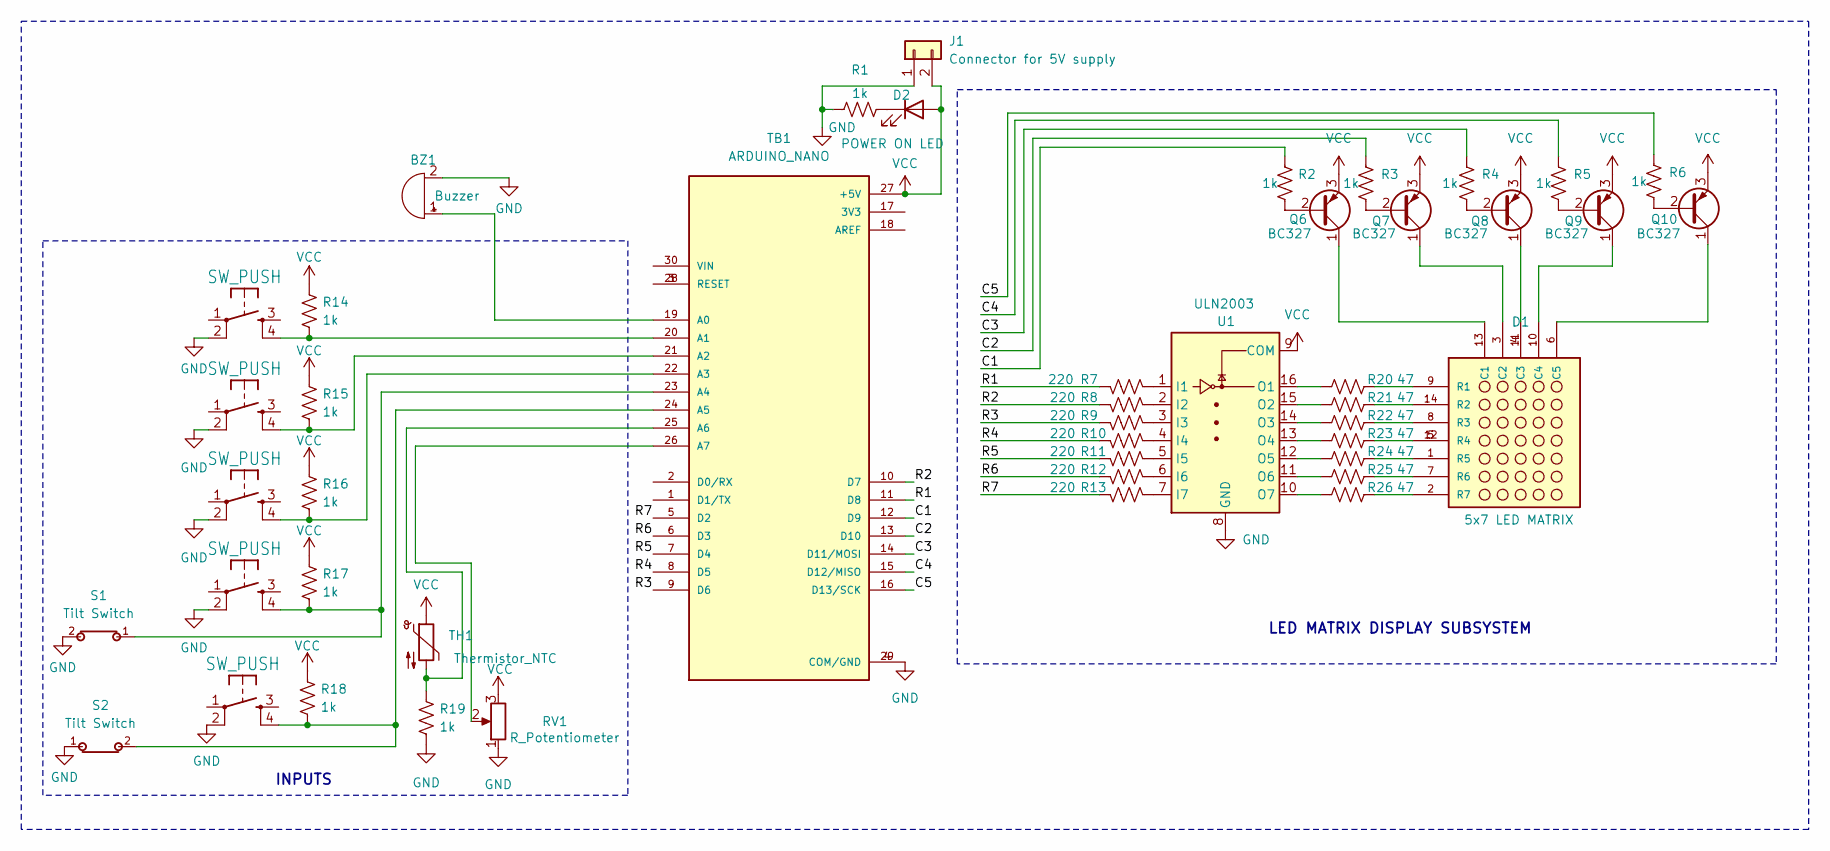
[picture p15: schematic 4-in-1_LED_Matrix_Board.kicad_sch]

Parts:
BZ1: Buzzer; XDCR_AT-1438-TWT-R
D1: 5x7 LED MATRIX; LED_TA20-11SRWA; PARTREV V.1A
D2: POWER ON LED; LED_D3.0mm
J1: Connector for 5V supply; JST_EH_B2B-EH-A_1x02_P2.50mm_Vertical
Q6, Q7, Q8, Q9, Q10: BC327; TO-92L_Inline_Wide
R1, R14, R15, R16, R17, R18, R19: 1k; R_Axial_DIN0204_L3.6mm_D1.6mm_P7.62mm_Horizontal
R2, R3, R4, R5, R6: 1k; R_Axial_DIN0207_L6.3mm_D2.5mm_P10.16mm_Horizontal
R7, R8, R9, R10, R11, R12, R13: 220; R_Axial_DIN0204_L3.6mm_D1.6mm_P7.62mm_Horizontal
R20, R21, R22, R23, R24, R25, R26: 47; R_Axial_DIN0204_L3.6mm_D1.6mm_P7.62mm_Horizontal
RV1: R_Potentiometer; RJ9W_2
S1, S2: Tilt Switch; SW-520D
SW1, SW2, SW3, SW4, SW5: SW_PUSH; B3F-40XX
TB1: ARDUINO_NANO; SHIELD_ARDUINO_NANO
TH1: Thermistor_NTC; THERM_GA50K6A1A
U1: ULN2003; DIP-16_W7.62mm

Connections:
/C1: R2.2, TB1.12 (D9)
/C2: R3.1, TB1.13 (D10)
/C3: R4.1, TB1.14 (D11/MOSI)
/C4: R5.1, TB1.15 (D12/MISO)
/C5: R6.1, TB1.16 (D13/SCK)
/R1: R7.1, TB1.11 (D8)
/R2: R8.1, TB1.10 (D7)
/R3: R9.1, TB1.9 (D6)
/R4: R10.1, TB1.8 (D5)
/R5: R11.1, TB1.7 (D4)
/R6: R12.1, TB1.6 (D3)
/R7: R13.1, TB1.5 (D2)
GND: BZ1.2 (-), J1.1, R1.1, R19.1, RV1.1, S1.2, S2.1, SW1.2 (P1), SW2.2 (P1), SW3.2 (P1), SW4.2 (P1), SW5.2 (P1), TB1.4 (COM/GND), TB1.29 (COM/GND), U1.8 (GND)
unnamed: BZ1.1 (+), TB1.19 (A0)
unnamed: D1.13 (C1), Q6.1 (C)
unnamed: D1.3 (C2), Q7.1 (C)
unnamed: D1.10 (C4), Q9.1 (C)
unnamed: D1.6 (C5), Q10.1 (C)
unnamed: D1.9 (R1), R20.1
unnamed: D1.14 (R2), R21.1
unnamed: D1.8 (R3), R22.1
unnamed: D1.5 (R4), D1.12 (R4), R23.1
unnamed: D1.1 (R5), R24.1
unnamed: D1.7 (R6), R25.1
unnamed: D1.2 (R7), R26.1
unnamed: D2.1 (K), R1.2
unnamed: Q6.2 (B), R2.1
unnamed: Q7.2 (B), R3.2
unnamed: Q8.2 (B), R4.2
unnamed: D1.4 (C3), D1.11 (C3), Q8.1 (C)
unnamed: Q9.2 (B), R5.2
unnamed: Q10.2 (B), R6.2
unnamed: R14.1, SW1.4 (S1), TB1.20 (A1)
unnamed: R15.1, SW2.4 (S1), TB1.21 (A2)
unnamed: R16.1, SW3.4 (S1), TB1.22 (A3)
unnamed: R17.1, S1.1, SW4.4 (S1), TB1.23 (A4)
unnamed: R18.1, S2.2, SW5.4 (S1), TB1.24 (A5)
unnamed: R19.2, TB1.25 (A6), TH1.2
unnamed: RV1.2, TB1.26 (A7)
unnamed: TB1.3 (RESET), TB1.28 (RESET)
unnamed: R7.2, U1.1 (I1)
unnamed: R8.2, U1.2 (I2)
unnamed: R9.2, U1.3 (I3)
unnamed: R10.2, U1.4 (I4)
unnamed: R11.2, U1.5 (I5)
unnamed: R12.2, U1.6 (I6)
unnamed: R13.2, U1.7 (I7)
unnamed: R20.2, U1.16 (O1)
unnamed: R21.2, U1.15 (O2)
unnamed: R22.2, U1.14 (O3)
unnamed: R23.2, U1.13 (O4)
unnamed: R24.2, U1.12 (O5)
unnamed: R25.2, U1.11 (O6)
unnamed: R26.2, U1.10 (O7)
VCC: D2.2 (A), J1.2, Q6.3 (E), Q7.3 (E), Q8.3 (E), Q9.3 (E), Q10.3 (E), R14.2, R15.2, R16.2, R17.2, R18.2, RV1.3, TB1.27 (+5V), TH1.1, U1.9 (COM)

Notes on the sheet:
INPUTS
LED MATRIX DISPLAY SUBSYSTEM

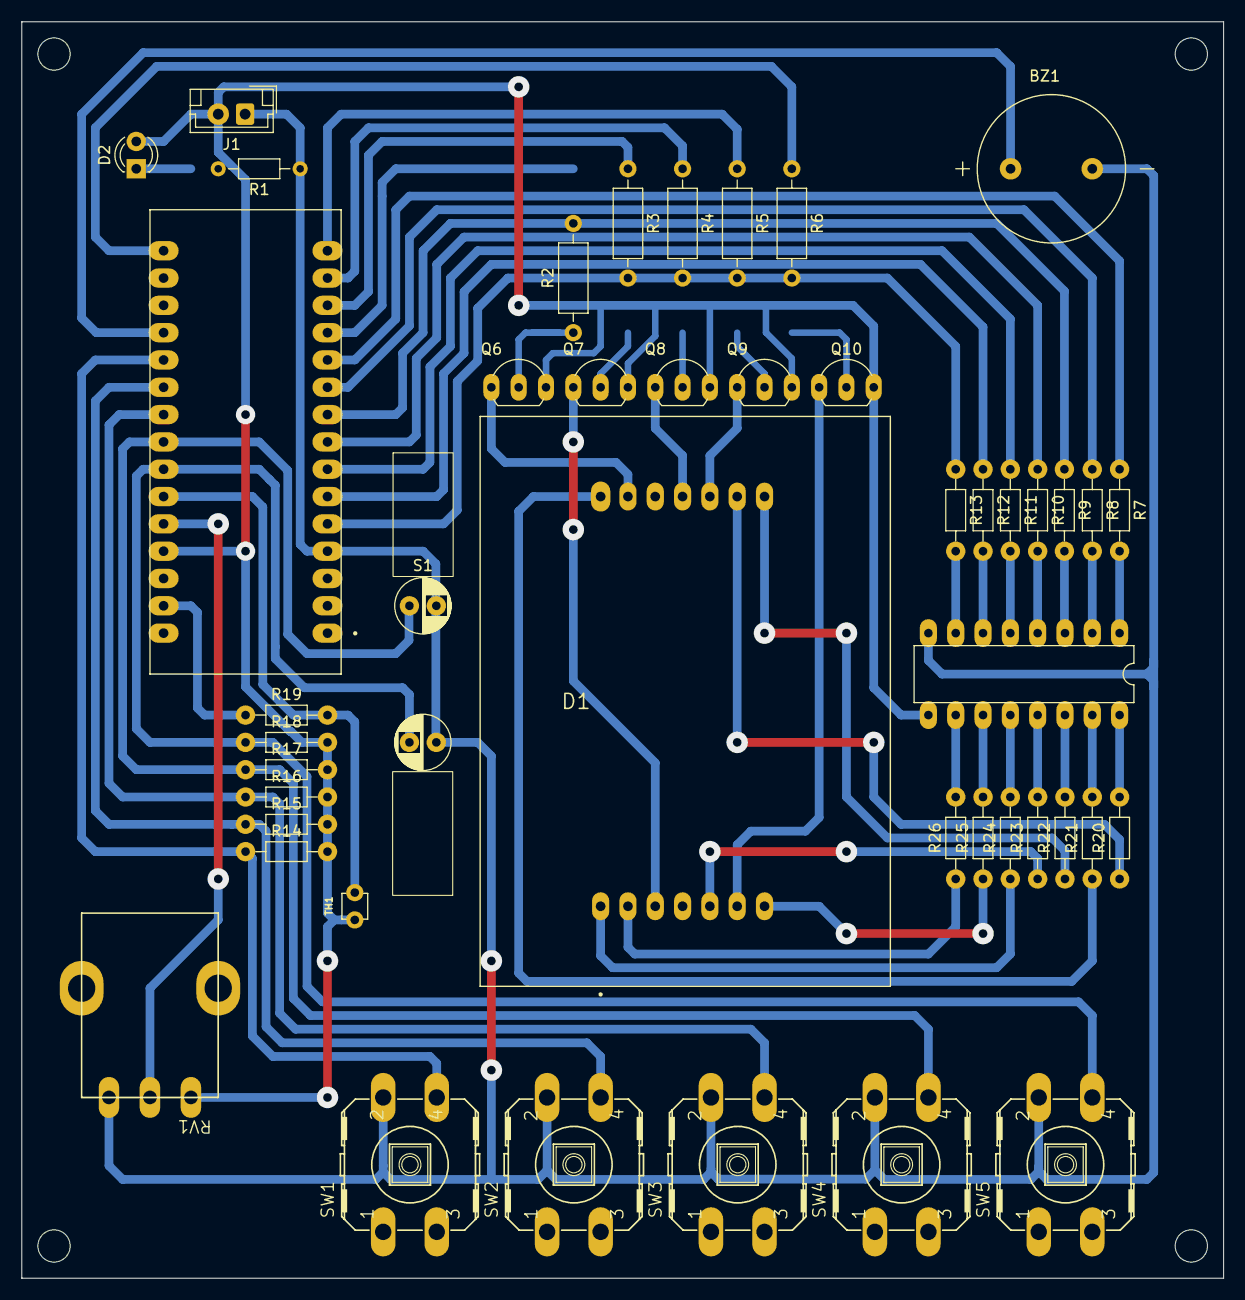
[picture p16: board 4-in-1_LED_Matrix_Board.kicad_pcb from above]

Board: 2 copper layers, 111.8 x 116.8 mm, 46 parts (0 on the bottom side), 55 nets.

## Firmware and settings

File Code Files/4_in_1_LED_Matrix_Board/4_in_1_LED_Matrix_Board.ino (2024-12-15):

// Pin configuration
const int rows[] = {8, 7, 6, 5, 4, 3, 2};
const int cols[] = {9, 10, 11, 12, 13};
const int buttonPin1 = A1;
const int buttonPin2 = A2;
const int buttonPin3 = A3;
const int tilt2 = A4;
const int tilt1 = A5;
const int buttonPin4 = A4;
const int buttonPin5= A5;
const int buzzerPin = A0;
const int potPin = A7;



const int thermistorPin = A6;
const int pullUpResistor = 1000;  // Pull-up resistor value (1kΩ)
const int R0 = 1000;              // Resistance of thermistor at 25°C (1kΩ)
const double Beta = 3950;         // Beta value
const double T0 = 298.15;         // Reference temperature in Kelvin (25°C)

// Bitmap for digits 0-9, 'C', and '.'
const byte digits[12][5] = {
  {B0111110, B1000101, B1001001, B1010001, B0111110}, // 0
  {B0000000, B0100001, B1111111, B0000001, B0000000}, // 1
  {B0100001, B1000011, B1000101, B1001001, B0110001}, // 2
  {B0100010, B1000001, B1001001, B1001001, B0110110}, // 3
  {B0001100, B0010100, B0100100, B1111111, B0000100}, // 4
  {B1111001, B1001001, B1001001, B1001001, B1000110}, // 5
  {B0111110, B1001001, B1001001, B1001001, B0000110}, // 6
  {B1000011, B1000100, B1001000, B1010000, B1100000}, // 7
  {B0110110, B1001001, B1001001, B1001001, B0110110}, // 8
  {B0110000, B1001001, B1001001, B1001001, B0111110}, // 9
  {B0111110, B1000001, B1000001, B1000001, B0100010}, // C
  {B0000000, B0000000, B0000010, B0000000, B0000000}  // Decimal point (.)
};

// Homescreen bitmaps: Morse Code and Hourglass
const byte homeScreen[5][5] = {
  {B0110100, B0110010, B0000010, B0110010, B0110100}, // Home
  {B0001000, B0000000, B0001000, B0001000, B0001000},  // Morse Code
  {B1100011, B1110111, B1111111, B1110111, B1100011},// Hourglass (Sandclock)
  {B0011100, B0100010, B0101010, B0100010, B0011100},// Persistance of Vision
  {B0000000, B0100000, B0001100, B0010010, B0010010}// Temprature
  
};

// Characters for Morse Code (to be filled by you)
const byte characters[36][5] = {
  {B0111111, B1001000, B1001000, B1001000, B0111111}, // A
  {B1111111, B1001001, B1001001, B1001001, B0110110}, // B
  {B0111110, B1000001, B1000001, B1000001, B0100010}, // C
  {B1111111, B1000001, B1000001, B1000001, B0111110}, // D
  {B1111111, B1001001, B1001001, B1001001, B1000001}, // E
  {B1111111, B1001000, B1001000, B1001000, B1000000}, // F
  {B0111110, B1000001, B1001001, B1001001, B0100110}, // G
  {B1111111, B0001000, B0001000, B0001000, B1111111}, // H
  {B0000000, B1000001, B1111111, B1000001, B0000000}, // I
  {B0000010, B0000001, B1000001, B1111110, B1000000}, // J
  {B1111111, B0001000, B0010100, B0100010, B1000001}, // K
  {B1111111, B0000001, B0000001, B0000001, B0000001}, // L
  {B1111111, B0100000, B0010000, B0100000, B1111111}, // M
  {B1111111, B0100000, B0010000, B0001000, B1111111}, // N
  {B0111110, B1000001, B1000001, B1000001, B0111110}, // O
  {B1111111, B1001000, B1001000, B1001000, B0110000}, // P
  {B0111110, B1000001, B1000101, B1000010, B0111101}, // Q
  {B1111111, B1001000, B1001100, B1001010, B0110001}, // R
  {B0110010, B1001001, B1001001, B1001001, B0100110}, // S
  {B1000000, B1000000, B1111111, B1000000, B1000000}, // T
  {B1111110, B0000001, B0000001, B0000001, B1111110}, // U
  {B1111100, B0000010, B0000001, B0000010, B1111100}, // V
  {B1111111, B0000010, B0001100, B0000010, B1111111}, // W
  {B1000001, B0100010, B0011100, B0100010, B1000001}, // X
  {B1000000, B0100000, B0011111, B0100000, B1000000}, // Y
  {B1000011, B1000101, B1001001, B1010001, B1100001}, // Z
  {B0111110, B1000101, B1001001, B1010001, B0111110}, // 0
  {B0000000, B0100001, B1111111, B0000001, B0000000}, // 1
  {B0100001, B1000011, B1000101, B1001001, B0110001}, // 2
  {B0100010, B1000001, B1001001, B1001001, B0110110}, // 3
  {B0001100, B0010100, B0100100, B1111111, B0000100}, // 4
  {B1111001, B1001001, B1001001, B1001001, B1000110}, // 5
  {B0111110, B1001001, B1001001, B1001001, B0000110}, // 6
  {B1000011, B1000100, B1001000, B1010000, B1100000}, // 7
  {B0110110, B1001001, B1001001, B1001001, B0110110}, // 8
  {B0110000, B1001001, B1001001, B1001001, B0111110}  // 9
};

// Morse code array: 1 = dot, 2 = dash, 0 = end of character
const byte morseCode[36][6] = {
 {1, 2, 0, 0, 0, 0}, // A: .-
  {2, 1, 1, 1, 0, 0}, // B: -...
  {2, 1, 2, 1, 0, 0}, // C: -.-.
  {2, 1, 1, 0, 0, 0}, // D: -..
  {1, 0, 0, 0, 0, 0}, // E: .
  {1, 1, 2, 1, 0, 0}, // F: ..-.
  {2, 2, 1, 0, 0, 0}, // G: --.
  {1, 1, 1, 1, 0, 0}, // H: ....
  {1, 1, 0, 0, 0, 0}, // I: ..
  {1, 2, 2, 2, 0, 0}, // J: .---
  {2, 1, 2, 0, 0, 0}, // K: -.-
  {1, 2, 1, 1, 0, 0}, // L: .-..
  {2, 2, 0, 0, 0, 0}, // M: --
  {2, 1, 0, 0, 0, 0}, // N: -.
  {2, 2, 2, 0, 0, 0}, // O: ---
  {1, 2, 2, 1, 0, 0}, // P: .--.
  {2, 2, 1, 2, 0, 0}, // Q: --.-
  {1, 2, 1, 0, 0, 0}, // R: .-.
  {1, 1, 1, 0, 0, 0}, // S: ...
  {2, 0, 0, 0, 0, 0}, // T: -
  {1, 1, 2, 0, 0, 0}, // U: ..-
  {1, 1, 1, 2, 0, 0}, // V: ...-
  {1, 2, 2, 0, 0, 0}, // W: .--
  {2, 1, 1, 2, 0, 0}, // X: -..-
  {2, 1, 2, 2, 0, 0}, // Y: -.--
  {2, 2, 1, 1, 0, 0}, // Z: --..
  // 0-9
  {2, 2, 2, 2, 2, 0}, // 0: -----
  {1, 2, 2, 2, 2, 0}, // 1: .----
  {1, 1, 2, 2, 2, 0}, // 2: ..---
  {1, 1, 1, 2, 2, 0}, // 3: ...--
  {1, 1, 1, 1, 2, 0}, // 4: ....-
  {1, 1, 1, 1, 1, 0}, // 5: .....
  {2, 1, 1, 1, 1, 0}, // 6: -....
  {2, 2, 1, 1, 1, 0}, // 7: --...
  {2, 2, 2, 1, 1, 0}, // 8: ---..
  {2, 2, 2, 2, 1, 0}  // 9: ----.
};

const byte patterns[][5] = {
    {B1100000, B1110000, B1110000, B1110000, B1100000},
    {B1100000, B1110000, B0111000, B1110000, B1100000},
    {B1100000, B1110000, B0110100, B1110000, B1100000},
    {B1100000, B1110000, B0110010, B1110000, B1100000},
    {B1100000, B1110000, B0110001, B1110000, B1100000},
    {B1100000, B1110000, B0111001, B0110000, B1100000},
    {B1100000, B1110000, B0110101, B0110000, B1100000},
    {B1100000, B1110000, B0110011, B0110000, B1100000},
    {B1100000, B1110000, B0110001, B0110001, B1100000},
    {B1100000, B0110000, B0111001, B0110001, B1100000},
    {B1100000, B0110000, B0110101, B0110001, B1100000},
    {B1100000, B0110000, B0110011, B0110001, B1100000},
    {B1100000, B0110001, B0110001, B0110001, B1100000},
    {B1100000, B0110001, B0111001, B0110001, B0100000},
    {B1100000, B0110001, B0110101, B0110001, B0100000},
    {B1100000, B0110001, B0110011, B0110001, B0100000},
    {B0100000, B0110001, B0111011, B0110001, B0100000},
    {B0100000, B0110001, B0110111, B0110001, B0100000},
    {B0100000, B0110001, B0110011, B0110011, B0100000},
    {B0100000, B0110001, B0110011, B0110001, B0100001},
    {B0100000, B0110001, B0011011, B0110001, B0100001},
    {B0100000, B0110001, B0010111, B0110001, B0100001},
    {B0100000, B0110011, B0010011, B0110001, B0100001},
    {B0100001, B0110001, B0010011, B0110001, B0100001},
    {B0100001, B0110001, B0010011, B0110001, B0100001},
    {B0100001, B0110001, B0011011, B0010001, B0100001},
    {B0100001, B0110001, B0010111, B0010001, B0100001},
    {B0100001, B0110001, B0010011, B0010011, B0100001},
    {B0100001, B0010001, B0011011, B0010011, B0100001},
    {B0100001, B0010001, B0010111, B0010011, B0100001},
    {B0100001, B0010011, B0010011, B0010011, B0100001},
    {B0100001, B0010011, B0011011, B0010011, B0000001},
    {B0100001, B0010011, B0010111, B0010011, B0000001},
    {B0000001, B0010011, B0011111, B0010011, B0000001},
    {B0000001, B0010011, B0010111, B0010111, B0000001},
    {B0000001, B0010011, B0010111, B0010011, B0000011},
    {B0000001, B0010011, B0011111, B0000011, B0000011},
    {B0000001, B0010111, B0010111, B0000011, B0000011},
    {B0000011, B0010011, B0010111, B0000011, B0000011},
    {B0000011, B0000011, B0011111, B0000011, B0000011},
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
};


// Reverse sand animation patterns
const byte reversePatterns[][5] = {
    {B0000011, B0000111, B0000111, B0000111, B0000011},
    {B0000011, B0000111, B0001110, B0000111, B0000011},
    {B0000011, B0000111, B0010110, B0000111, B0000011},
    {B0000011, B0000111, B0100110, B0000111, B0000011},
    {B0000011, B0000111, B1000110, B0000111, B0000011},
    {B0000011, B0000111, B1001110, B0000110, B0000011},
    {B0000011, B0000111, B1010110, B0000110, B0000011},
    {B0000011, B0000111, B1100110, B0000110, B0000011},
    {B0000011, B0000111, B1000110, B1000110, B0000011},
    {B0000011, B0000110, B1001110, B1000110, B0000011},
    {B0000011, B0000110, B1010110, B1000110, B0000011},
    {B0000011, B0000110, B1100110, B1000110, B0000011},
    {B0000011, B1000110, B1000110, B1000110, B0000011},
    {B0000011, B1000110, B1001110, B1000110, B0000010},
    {B0000011, B1000110, B1010110, B1000110, B0000010},
    {B0000011, B1000110, B1100110, B1000110, B0000010},
    {B0000010, B1000110, B1101110, B1000110, B0000010},
    {B0000010, B1000110, B1110110, B1000110, B0000010},
    {B0000010, B1000110, B1100110, B1100110, B0000010},
    {B0000010, B1000110, B1100110, B1000110, B1000010},
    {B0000010, B1000110, B1101100, B1000110, B1000010},
    {B0000010, B1000110, B1110100, B1000110, B1000010},
    {B0000010, B1100110, B1100100, B1000110, B1000010},
    {B1000010, B1000110, B1100100, B1000110, B1000010},
    {B1000010, B1000110, B1101100, B1000100, B1000010},
    {B1000010, B1000110, B1110100, B1000100, B1000010},
    {B1000010, B1000110, B1100100, B1100100, B1000010},
    {B1000010, B1000100, B1101100, B1100100, B1000010},
    {B1000010, B1000100, B1110100, B1100100, B1000010},
    {B1000010, B1100100, B1100100, B1100100, B1000010},
    {B1000010, B1100100, B1101100, B1100100, B1000000},
    {B1000010, B1100100, B1110100, B1100100, B1000000},
    {B1000000, B1100100, B1111100, B1100100, B1000000},
    {B1000000, B1100100, B1110100, B1110100, B1000000},
    {B1000000, B1100100, B1110100, B1100100, B1100000},
    {B1000000, B1100100, B1111000, B1100100, B1100000},
    {B1000000, B1110100, B1110000, B1100100, B1100000},
    {B1100000, B1100100, B1110000, B1100100, B1100000},
    {B1100000, B1100100, B1111000, B1100000, B1100000},
    {B1100000, B1100100, B1110000, B1110000, B1100000},
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

};

const byte A[5] = {
    B0111111,  // Col 1
    B1001000,  // Col 2
    B1001000,  // Col 3
    B1001000,  // Col 4
    B0111111,  // Col 5
};
// Bitmap for digits 0-9, 'C', and '.'
const byte Temp[12][5] = {
  {B0111110, B1000101, B1001001, B1010001, B0111110}, // 0
  {B0000000, B0100001, B1111111, B0000001, B0000000}, // 1
  {B0100001, B1000011, B1000101, B1001001, B0110001}, // 2
  {B0100010, B1000001, B1001001, B1001001, B0110110}, // 3
  {B0001100, B0010100, B0100100, B1111111, B0000100}, // 4
  {B1111001, B1001001, B1001001, B1001001, B1000110}, // 5
  {B0111110, B1001001, B1001001, B1001001, B0000110}, // 6
  {B1000011, B1000100, B1001000, B1010000, B1100000}, // 7
  {B0110110, B1001001, B1001001, B1001001, B0110110}, // 8
  {B0110000, B1001001, B1001001, B1001001, B0111110}, // 9
  {B0111110, B1000001, B1000001, B1000001, B0100010}, // C
  {B0000000, B0000000, B0000010, B0000000, B0000000}  // Decimal point (.)
};

// Global variables
volatile int currentProgramIndex = 0;
volatile int currentCharacterIndex = 0;
volatile int currentColumn = 0;
volatile int potValue = 0;       // Potentiometer value
static bool wasPOVmode = false;
bool morseMode = false;
bool hourglassMode = false;
bool POVmode = false;
bool tempMode = false;



bool buttonState1 = false;
bool lastButtonState1 = false;
bool buttonState2 = false;
bool lastButtonState2 = false;
bool buttonState3 = false;
bool lastButtonState3 = false;
bool buttonState4 = false;
bool lastButtonState4 = false;
bool buttonState5 = false;
bool lastButtonState5 = false;

const int numFrames1 = sizeof(patterns) / sizeof(patterns[0]);
const int numFrames2 = sizeof(reversePatterns) / sizeof(reversePatterns[0]);

int currentFrame = 0;
volatile bool updateFrame = false;
const long transitionTime = 5000;
long frameDelay1;
long frameDelay2;
bool animationComplete = false;
bool reverseMode = false;

volatile unsigned long lastBuzzerToggle = 0;
bool buzzerState = false;
bool buzzerOn = false;
unsigned long button1PressStart = 0; // Tracks when the button was pressed
bool button1LongPressDetected = false; // Flag to avoid multiple triggers

volatile byte buffer[50] = {0};  // Scrolling buffer for display
volatile int offset = 0;         // Offset for scrolling
volatile bool updateScroll = false;
const int scrollInterval = 150;  // Scrolling speed in ms
unsigned long lastScrollTime = 0;

void setup() {
  Serial.begin(9600);

  // Pin setup
  for (int i = 0; i < 7; i++) pinMode(rows[i], OUTPUT);
  for (int i = 0; i < 5; i++) pinMode(cols[i], OUTPUT);
  pinMode(buttonPin1, INPUT_PULLUP);
  pinMode(buttonPin2, INPUT_PULLUP);
  pinMode(buttonPin3, INPUT_PULLUP);
  pinMode(buzzerPin, OUTPUT);
  pinMode(tilt2, INPUT);
  pinMode(tilt1, INPUT);

  frameDelay1 = transitionTime / numFrames1;
  frameDelay2 = transitionTime / numFrames2;

  // Timer1 setup for LED refresh
  cli();
  TCCR1A = 0;
  TCCR1B = 0;
  TCNT1 = 0;
  OCR1A = 249;  // Compare match value for 10ms (16MHz clock, prescaler 64)
  TCCR1B |= (1 << WGM12); // CTC mode
  TCCR1B |= (1 << CS11) | (1 << CS10); // Prescaler 64
  TIMSK1 |= (1 << OCIE1A);
  sei();
}

void loop() {
    // Read buttons
    buttonState1 = digitalRead(buttonPin1);
    buttonState2 = digitalRead(buttonPin2);
    buttonState3 = digitalRead(buttonPin3);
    buttonState4 = digitalRead(buttonPin4);
    buttonState5 = digitalRead(buttonPin5);

    bool tiltDown = !digitalRead(tilt2);
    bool tiltUp = !digitalRead(tilt1);
    static float lastTemperature = 0.0;  
    // Handle Button 1 Long Press for Home Screen
    if (buttonState1 == LOW && lastButtonState1 == HIGH) {
        button1PressStart = millis(); // Start the timer
        button1LongPressDetected = false; // Reset the flag
    }

    if (buttonState1 == LOW && millis() - button1PressStart >= 5000 && !button1LongPressDetected) {
        button1LongPressDetected = true;
        morseMode = hourglassMode = POVmode = tempMode = false;
        currentProgramIndex = 0; // Reset to home screen
        resetAnimation();
        clearAllLeds();
        Serial.println("Returned to Home Screen");
    }

    if (buttonState1 == HIGH && lastButtonState1 == LOW) {
        button1PressStart = 0; // Reset the timer
    }

    // Home Screen Navigation
    if (!morseMode && !hourglassMode && !POVmode && !tempMode) {
        if (lastButtonState1 == HIGH && buttonState1 == LOW) {
            currentProgramIndex = (currentProgramIndex + 1) % 5; // Move forward
            delay(100);
        }
        if (lastButtonState2 == HIGH && buttonState2 == LOW) {
            currentProgramIndex = (currentProgramIndex - 1 + 5) % 5; // Move backward
            delay(100);
        }
        if (lastButtonState3 == HIGH && buttonState3 == LOW) {
            // Select program
            if (currentProgramIndex == 1) morseMode = true;
            else if (currentProgramIndex == 2) hourglassMode = true;
            else if (currentProgramIndex == 3) POVmode = true;
            else if (currentProgramIndex == 4) {
                tempMode = true;
                offset = 0; // Reset scrolling offset
                lastScrollTime = millis(); // Reset scroll timing
            }
            delay(200);
        }
    }

    // Morse Mode Tutor Logic
    else if (morseMode) {
        if (lastButtonState1 == HIGH && buttonState1 == LOW) {
            currentCharacterIndex = (currentCharacterIndex + 1) % 36;
            delay(100);
        }
        if (lastButtonState2 == HIGH && buttonState2 == LOW) {
            currentCharacterIndex = (currentCharacterIndex - 1 + 36) % 36;
            delay(100);
        }
        if (lastButtonState3 == HIGH && buttonState3 == LOW) {
            playMorse(currentCharacterIndex);
            delay(100);
        }
    }

    // Hourglass Mode Logic
    else if (hourglassMode) {
        if (updateFrame) {
            if (tiltDown && !animationComplete && !reverseMode) smoothSandDown();
            if (tiltUp && !animationComplete && reverseMode) smoothSandUp();
            if (animationComplete) {
                buzzerOn = true;
                ringBuzzer();
            }
            if (tiltUp && !reverseMode) {
                reverseMode = true;
                resetAnimation();
            }
            if (tiltDown && reverseMode) {
                reverseMode = false;
                resetAnimation();
            }
        }
    }

    // Temperature Display Logic
    else if (tempMode) {
        if (millis() - lastScrollTime >= scrollInterval) {
            lastScrollTime = millis(); // Update scroll timer
            offset++; // Move scroll offset
            if (offset >= sizeof(buffer)) {
                offset = 0; // Reset scrolling
            }
            lastTemperature = calculateTemperature(); // Update temperature
            prepareBuffer(lastTemperature); // Prepare buffer
            Serial.print("Temperature: ");
            Serial.println(lastTemperature);
        }
    }
if (!POVmode && wasPOVmode) {
    OCR1A = 249;  // Reset Timer1 compare value to default (~10ms)
}

wasPOVmode = POVmode;
    // Update last button states
    lastButtonState1 = buttonState1;
    lastButtonState2 = buttonState2;
    lastButtonState3 = buttonState3;
    lastButtonState4 = buttonState4;
    lastButtonState5 = buttonState5;
}



// Optimized Timer1 ISR for smooth multiplexing
ISR(TIMER1_COMPA_vect) {
    static int colIndex = 0;
    static int potValue = 0;
    static int counter = 0;
    updateFrame = true;

    // Clear previous column
    digitalWrite(cols[colIndex], HIGH);
    for (int row = 0; row < 7; row++) {
        digitalWrite(rows[row], LOW);
    }

    // Move to the next column
    colIndex = (colIndex + 1) % 5;

    // Display content based on active mode
    if (POVmode) {
        // Read potentiometer every 50ms
        if (counter++ >= 10) {
            potValue = analogRead(potPin);
            OCR1A = map(potValue, 0, 1023, 499, 24999); // Adjusts interval dynamically
            counter = 0;
        }

        // Activate the rows for the new column based on the dynamic pattern
        for (int row = 0; row < 7; row++) {
            if (A[colIndex] & (1 << (6 - row))) { // Check if the bit is set in the pattern
                digitalWrite(rows[row], HIGH);   // Turn on the corresponding row
            }
        }
  
    } else if (hourglassMode) {
        // Hourglass animation logic
        byte pattern = reverseMode ? reversePatterns[currentFrame][colIndex] : patterns[currentFrame][colIndex];
        for (int row = 0; row < 7; row++) {
            digitalWrite(rows[row], (pattern & (1 << (6 - row))) ? HIGH : LOW);
        }
    } else if (morseMode) {
        // Morse code display logic
        byte pattern = characters[currentCharacterIndex][colIndex];
        for (int row = 0; row < 7; row++) {
            digitalWrite(rows[row], (pattern & (1 << (6 - row))) ? HIGH : LOW);
        }
    } else if (tempMode) {
        // Temperature scrolling logic
        byte pattern = buffer[(colIndex + offset) % sizeof(buffer)];
        for (int row = 0; row < 7; row++) {
            digitalWrite(rows[row], (pattern & (1 << (6 - row))) ? HIGH : LOW);
        }
    } else {
        // Home screen logic
        byte pattern = homeScreen[currentProgramIndex][colIndex];
        for (int row = 0; row < 7; row++) {
            digitalWrite(rows[row], (pattern & (1 << (6 - row))) ? HIGH : LOW);
        }
    }

    // Activate the new column
    digitalWrite(cols[colIndex], LOW);
}


void playMorse(int index) {
  for (int i = 0; morseCode[index][i] != 0; i++) {
    noTone(buzzerPin);
    if (morseCode[index][i] == 1) {
      tone(buzzerPin, 2000, 200);
      delay(700);
    } else if (morseCode[index][i] == 2) {
      tone(buzzerPin, 2000, 600);
      delay(1100);
    }
  }
  noTone(buzzerPin);
}
void smoothSandDown() {
    static unsigned long lastFrameTime = 0;
    if (millis() - lastFrameTime >= frameDelay1) {
        lastFrameTime = millis();
        if (currentFrame < numFrames1 - 1) {
            currentFrame++;
        } else {
            animationComplete = true;
        }
    }
}

void smoothSandUp() {
    static unsigned long lastFrameTime = 0;
    if (millis() - lastFrameTime >= frameDelay2) {
        lastFrameTime = millis();
        if (currentFrame < numFrames2 - 1) {
            currentFrame++;
        } else {
            animationComplete = true;
        }
    }
}

void resetAnimation() {
    animationComplete = false;
    buzzerOn = false;
    currentFrame = 0;
    clearAllLeds();
    noTone(buzzerPin);  // Explicitly stop the buzzer
}

void ringBuzzer(){
    if (buzzerOn) {
        tone(buzzerPin, 4000); // Generate a 1kHz tone
    } 
    else{
        noTone(buzzerPin);}  // Ensure the tone is stopped
}
void clearAllLeds() {
    for (int col = 0; col < 5; col++) {
        digitalWrite(cols[col], HIGH);
        for (int row = 0; row < 7; row++) {
            digitalWrite(rows[row], LOW);
        }
    }
}
// Calculate temperature
double calculateTemperature() {
  long sensorValue = analogRead(thermistorPin);
  double voltage = sensorValue * (5.0 / 1023.0);
  double thermistorResistance = pullUpResistor * ((5.0 - voltage) / voltage);
  double temperatureKelvin = 1.0 / ((1.0 / T0) + (1.0 / Beta) * log(thermistorResistance / R0));
  return temperatureKelvin - 273.15;
}

// Scroll temperature data into buffer
void prepareBuffer(float temperature) {
  char tempString[7];
  dtostrf(temperature, 4, 1, tempString);
  strcat(tempString, " C");

  int bufferIndex = 0;
  memset(buffer, 0, sizeof(buffer));

  for (int i = 0; tempString[i] != '\0'; i++) {
    int digit = (tempString[i] >= '0' && tempString[i] <= '9') ? tempString[i] - '0' :
                (tempString[i] == 'C') ? 10 :
                (tempString[i] == '.') ? 11 : -1;

    if (digit >= 0) {
      for (int col = 0; col < 5; col++) {
        buffer[bufferIndex++] = digits[digit][col];
      }
      buffer[bufferIndex++] = 0;  // Spacing
    }
  }
}
